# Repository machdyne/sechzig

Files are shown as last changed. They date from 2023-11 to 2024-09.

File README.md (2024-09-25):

# Sechzig Compute Module

Sechzig is a work-in-progress compute module specification.

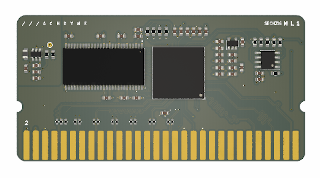
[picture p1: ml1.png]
Sechzig ML1


Sechzig modules have a 60-pin 2.54mm card edge connector.

This repo contains detailed specifications as well as relevant KiCad symbols and footprints.

## Specifications

### Signals

This section describes the signals from the perspective of the module when paired with [Mozart](https://github.com/machdyne/mozart).

| Signal | Voltage | Dir | Description |
| --- | --- | --- | --- |
| PWR5V0 | 5.0V | I | System power (2A max) |
| PWR3V3 | 3.3V | I | System power (1A max) |
| PWRIO | 2.5V - 3.3V | O | I/O power (1A max) |
| SYS\_PG | 3.3V | I | System power good |
| SYS\_RST\_N | PWRIO | I | System reset (active low) |
| SYS\_CLK48 | PWRIO | I | System clock (48MHz) |
| USBD\_Dx | 3.3V | IO | USB device interface |
| USBHx\_Dx | 3.3V | IO | USB host interfaces |
| AUD\_DAT | PWRIO | O | Audio data |
| AUD\_BCK | PWRIO | O | Audio clock |
| AUD\_WS | PWRIO | O | Audio word select |
| ETH\_TXx | PWRIO | O | Ethernet RMII PHY transmit data |
| ETH\_RXx | PWRIO | I | Ethernet RMII PHY receive data |
| ETH\_TXEN | PWRIO | O | Ethernet RMII PHY transmit enable |
| ETH\_CRS\_DV | PWRIO | I | Ethernet RMII PHY carrier sense / receive data valid |
| ETH\_RST\_N | PWRIO | O | Ethernet RMII PHY reset (active low) |
| ETH\_CLK50 | PWRIO | I | Ethernet/video clock (50MHz) |
| DDMI\_xx\_x | 3.3V | O | [DDMI](https://github.com/machdyne/ddmi) interface |
| Xx | PWRIO | IO | Extra link (see notes below) |
| SD\_CD\_N | 3.3V | I | SD card detect (active low) |
| SD\_SS | 3.3V | IO | SD slave select / DAT3 |
| SD\_SCK | 3.3V | O | SD clock |
| SD\_MISO | 3.3V | IO | SD data output / DAT0 |
| SD\_MOSI | 3.3V | IO | SD data input / CMD |
| SD\_D1 | 3.3V| IO | SD DAT1 |
| SD\_D2 | 3.3V | IO | SD DAT2 |
| JTAG\_xxx | PWRIO | IO | JTAG interface |
| UART\_TX | PWRIO | O | UART transmit |
| UART\_RX | PWRIO | I | UART receive |
| DSx\_x | 2.5V | IO | Experimental high-speed link (see notes below) |

#### Signal Notes

  * While all Sechzig modules should be compatible with [Mozart](https://github.com/machdyne/mozart), it is possible to develop alternative host boards that use some signals for other purposes (see [Vivaldi](https://github.com/machdyne/vivaldi) and [Chopin](https://github.com/machdyne/chopin)).

##### Extra Link (Xx) Notes

The purpose of the Xx signals is determined by the host board. For example, on Mozart:

| Signal | Description |
| --- | --- |
| XA | SPI MISO / I2C SCL |
| XB | SPI SCK / I2C SDA |
| XC | SPI MOSI |
| XD | SPI SS |

##### Experimental High-Speed Link (DSx) Notes

The DSx signal traces are routed as length-matched 100 ohm differential pairs. The following minimum required configuration should be supported by all modules, but some modules may have additional capabilities:

| Signal | Standard | Dir | Required | Description |
| --- | --- | --- | --- | --- |
| DS0\_x | LVDS25 | IO | N | Transmit and/or Receive |
| DS1\_x | LVDS25 | O | Y | Transmit |
| DS2\_x | LVDS25 | I | Y | Receive |

### Power

Sechzig modules can operate with 2.5V or 3.3V I/O (note that some signals must be 2.5V and 3.3V on all modules). Modules that use 3.3V I/O can simply connect PWRIO to PWR3V3. Modules that use 2.5V I/O must provide 2.5V on PWRIO.

### Module Dimensions

| Dimension | Value |
| --- | ----- |
| Width | 79mm |
| Height | 50mm max |
| Depth | 8mm max (4mm from center) |
| Card Edge Depth | 1.4mm - 1.6mm |

### Board Revisions

The version number can be found on the back of the module.

#### ML1

Product page for [Sechzig ML1](https://machdyne.com/product/sechzig-ml1-compute-module/).

| Revision | Stackup | Notes |
| --- | --- | ----- |
| ML1.1 | Aisler 4L | Initial production version; **Xx signals are not connected** |
| ML1.2 | Aisler 4L | Current production version; connects Xx signals; adds LED |

#### ML2

Product page for [Sechzig ML2](https://machdyne.com/product/sechzig-ml2-compute-module/).

| Revision | Stackup | Notes |
| --- | --- | ----- |
| ML2.0 | Aisler 6L | Initial production version |
| ML2.0B | JLC06161H-3313 | Current production version |

#### MX1

Product page for [Sechzig MX1](https://machdyne.com/product/sechzig-mx1-compute-module/).

| Revision | Stackup | Notes |
| --- | --- | ----- |
| MX1.1 | Aisler 4L | Initial production version |

#### MX2

Product page for [Sechzig MX2](https://machdyne.com/product/sechzig-mx2-compute-module/).

| Revision | Stackup | Notes |
| --- | --- | ----- |
| MX2.0 | JLC06161H-3313 | Initial production version |

## Funding

This project was partially funded through the NGI0 Entrust Fund, a fund established by NLnet with financial support from the European Commission's Next Generation Internet programme.

## License

This project is released under the [CERN-OHL-P](LICENSE.txt) license.

Note: You can use these designs for commercial purposes but we ask that instead of producing exact clones, that you either replace our trademarks and logos with your own or add your own next to ours.

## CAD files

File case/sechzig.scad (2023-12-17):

/*
 * Sechzig Case
 * Copyright (c) 2023 Lone Dynamics Corporation. All rights reserved.
 *
 * required hardware:
 *  - 2 x M3 x 16MM countersunk bolts
 *  - 2 x M3 nuts
 *
 */

$fn = 100;

board_depth = 1.6;
board_height = 40;

//translate([0,-2.5,6]) sechzig_module();
//rotate([180,0,180]) translate([0,0,-12]) sechzig_front();
sechzig_back();

module sechzig_module() {
	difference() {
		//color([0,1,0]) cube([79,50,8], center=true);
		color([0,1,0]) cube([79,board_height,8], center=true);
		translate([79/2,-50/2+15,-10]) cylinder(d=3, h=50);
		translate([-79/2,-50/2+15,-10]) cylinder(d=3, h=50);
	}
}

module sechzig_front() {
	
	//	color([0,1,0]) translate([0,0,6]) cube([80,53,board_depth], center=true);
	
	difference() {

		union() {
			translate([-95/2,-60/2+1.5,0]) roundedcube(95,board_height+10,6-(board_depth/2),2.5);
			translate([0,0,1.6]) cube([95+2,10,6-(board_depth/2)+2], center=true);
		}
				
		// module component cutout
		translate([0,0,6-(board_depth/2)]) cube([78,board_height+0.5,8.4], center=true);
		
		// bottom opening
		translate([0,-55/2+3.5,6]) cube([93,9.5,12-2], center=true);
	
		// vents
		translate([-5,12,0]) rotate([0,0,15]) cube([1,8,8], center=true);
		translate([0,12,0]) rotate([0,0,15]) cube([1,8,8], center=true);
		translate([5,12,0]) rotate([0,0,15]) cube([1,8,8], center=true);
		
		// bolt holes
		translate([-43.5,0,-2]) cylinder(d=3.2, h=100);
		translate([43.5,0,-2]) cylinder(d=3.2, h=100);
		
		// bolt countersink holes
		translate([-43.5,0,-2]) cylinder(d=6, h=1);
		translate([43.5,0,-2]) cylinder(d=6, h=1);
	
		rotate([0,180,0])
			translate([0,-2,1.5])
				linear_extrude(1)
					text("S E C H Z I G  M L 1", size=4, halign="center",
						font="Liberation Sans:style=Bold");

	}
		
}

module sechzig_back() {
		
//	color([0,1,0]) translate([0,0,6]) cube([80,53,board_depth], center=true);
	
	difference() {
		union() {
			translate([-95/2,-60/2+1.5,0]) roundedcube(95,board_height+10,6+(board_depth/2),2.5);
			translate([0,0,2.4]) cube([95+2,10,6+(board_depth/2)+2], center=true);
			
			// guide notches
			translate([20,-3.5,-1])
				cube([9.5,board_height+10,2], center=true);
				
			translate([-20,-3.5,-1])
				cube([9.5,board_height+10,2], center=true);

		}
		
		// module board cutout
		translate([0,0,6]) cube([79+0.5,board_height+0.5,board_depth], center=true);		

		// board notch adjacent cutouts
		translate([79/2-0.75,-55/2+15-2,3.8]) cube([2,2,5.6], center=true);
		translate([79/2-0.75,-55/2+15+2,3.8]) cube([2,2,5.6], center=true);
		translate([-79/2+0.75,-55/2+15-2,3.8]) cube([2,2,5.6], center=true);
		translate([-79/2+0.75,-55/2+15+2,3.8]) cube([2,2,5.6], center=true);
		
		
		// module component cutout
		translate([0,0,6]) cube([78,board_height+0.5,12-2], center=true);
		
		// bottom opening
		translate([0,-55/2+3.5,6]) cube([93,9.5,12-2], center=true);
		
		// vents
		translate([-5,12,0]) rotate([0,0,15]) cube([1,8,8], center=true);
		translate([0,12,0]) rotate([0,0,15]) cube([1,8,8], center=true);
		translate([5,12,0]) rotate([0,0,15]) cube([1,8,8], center=true);

		// bolt holes
		translate([-43.5,0,-2]) cylinder(d=3.2, h=100);
		translate([43.5,0,-2]) cylinder(d=3.2, h=100);
		
		// nut holes
		translate([-43.5,0,-2.5]) rotate([0,0,30]) cylinder(d=7, h=2.5, $fn=6);
		translate([43.5,0,-2.5]) rotate([0,0,30]) cylinder(d=7, h=2.5, $fn=6);
	
		rotate([0,180,0])
			translate([0,-2,1.5])
				linear_extrude(1)
					text("M L 1", size=4, halign="center",
						font="Liberation Sans:style=Bold");

	}

	// board notches
	translate([79/2+0.25,-55/2+15,3.8]) cylinder(d=2.75, h=6, center=true);
	translate([-79/2-0.25,-55/2+15,3.8]) cylinder(d=2.75, h=6, center=true);

}

// https://gist.github.com/tinkerology/ae257c5340a33ee2f149ff3ae97d9826
module roundedcube(xx, yy, height, radius)
{
    translate([0,0,height/2])
    hull()
    {
        translate([radius,radius,0])
        cylinder(height,radius,radius,true);

        translate([xx-radius,radius,0])
        cylinder(height,radius,radius,true);

        translate([xx-radius,yy-radius,0])
        cylinder(height,radius,radius,true);

        translate([radius,yy-radius,0])
        cylinder(height,radius,radius,true);
    }
}

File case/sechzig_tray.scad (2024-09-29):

/*
 * Sechzig Tray
 * Copyright (c) 2024 Lone Dynamics Corporation. All rights reserved.
 *
 */

$fn = 100;

board_length = 79 + 0.75;
board_thickness = 1.85;
board_width = 8 + 2;

boards = 8;

sechzig_tray();

module sechzig_tray() {
	
	length = board_length + 5;
	width = board_width * boards + 10;
	
	difference() {
		
		translate([-length/2,-width/2,-3/2]) roundedcube(length, width, 10, 5);
		
		for ( i = [0:boards-1] ) {
			translate([0,width/2-5-(i*board_width),13.5-8])
				cube([board_length, board_thickness, 10], center=true);
		}
		
		translate([length/2-20,-width/2+5,7.75])
			linear_extrude(2)
				text("S E C H Z I G", size=4, halign="center",
					font="Lato:style=Bold");

		translate([-length/2+10,-width/2+5,7.75])
			linear_extrude(2)
				text("/ / /", size=4, halign="center",
					font="Lato:style=Bold");
	
		
	}
	
}

// https://gist.github.com/tinkerology/ae257c5340a33ee2f149ff3ae97d9826
module roundedcube(xx, yy, height, radius)
{
    translate([0,0,height/2])
    hull()
    {
        translate([radius,radius,0])
        cylinder(height,radius,radius,true);

        translate([xx-radius,radius,0])
        cylinder(height,radius,radius,true);

        translate([xx-radius,yy-radius,0])
        cylinder(height,radius,radius,true);

        translate([radius,yy-radius,0])
        cylinder(height,radius,radius,true);
    }
}

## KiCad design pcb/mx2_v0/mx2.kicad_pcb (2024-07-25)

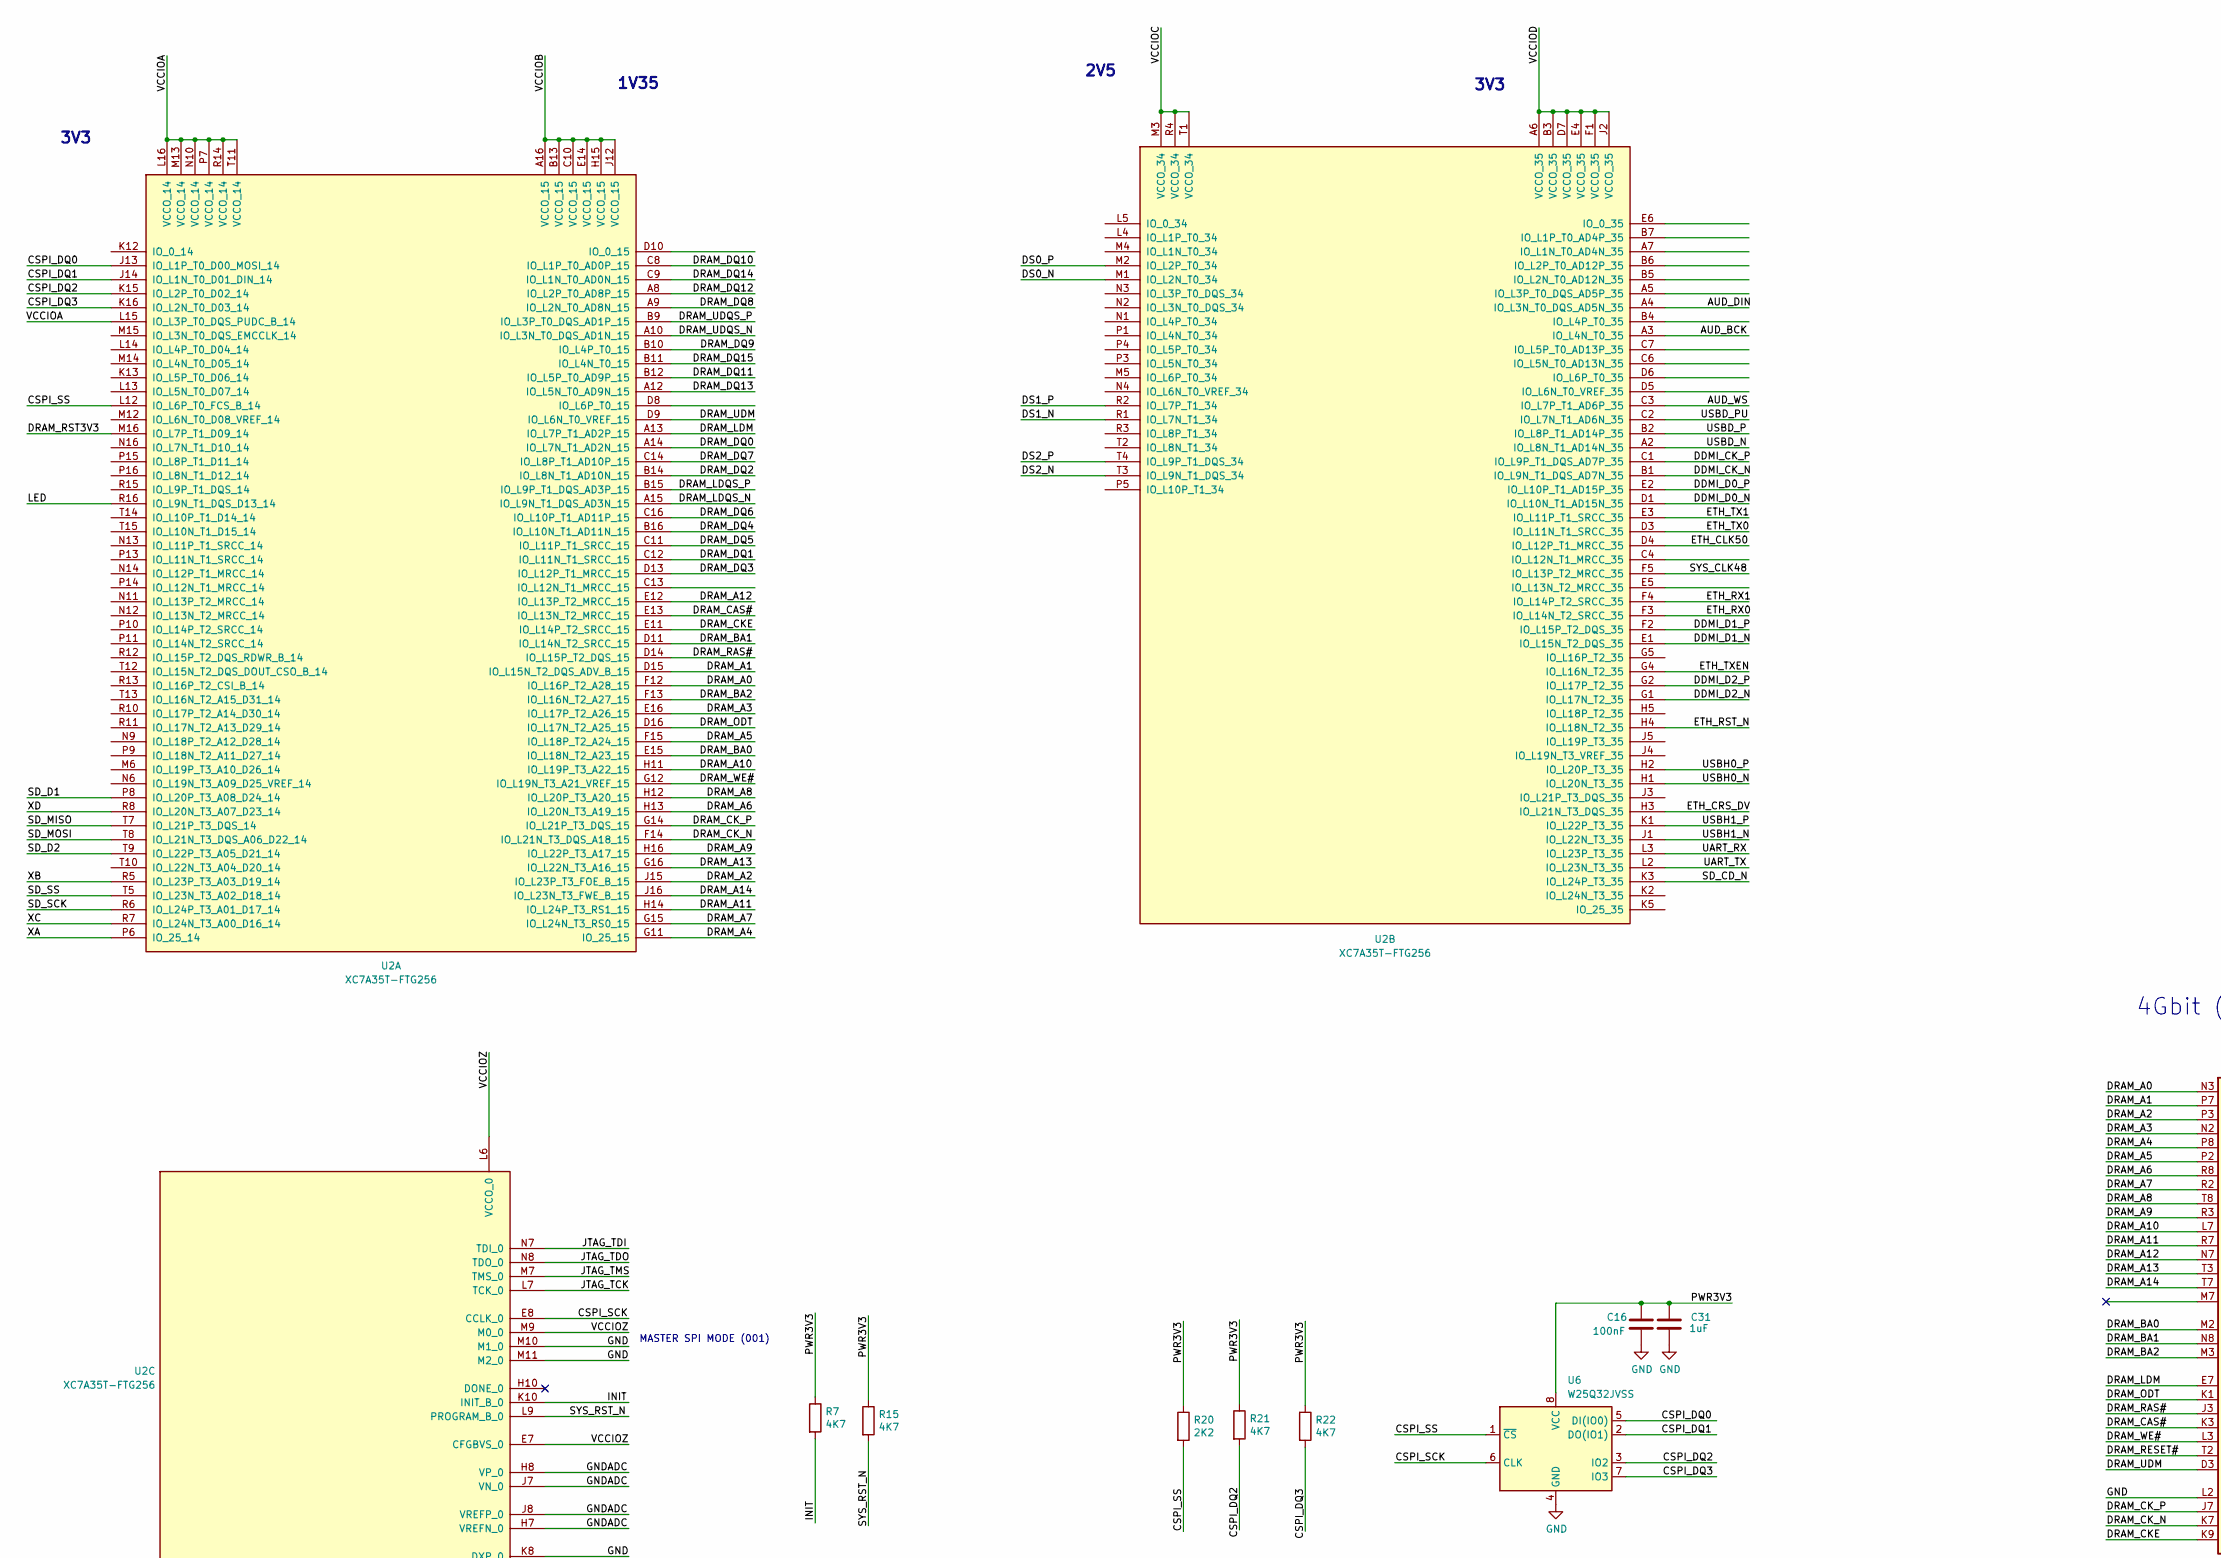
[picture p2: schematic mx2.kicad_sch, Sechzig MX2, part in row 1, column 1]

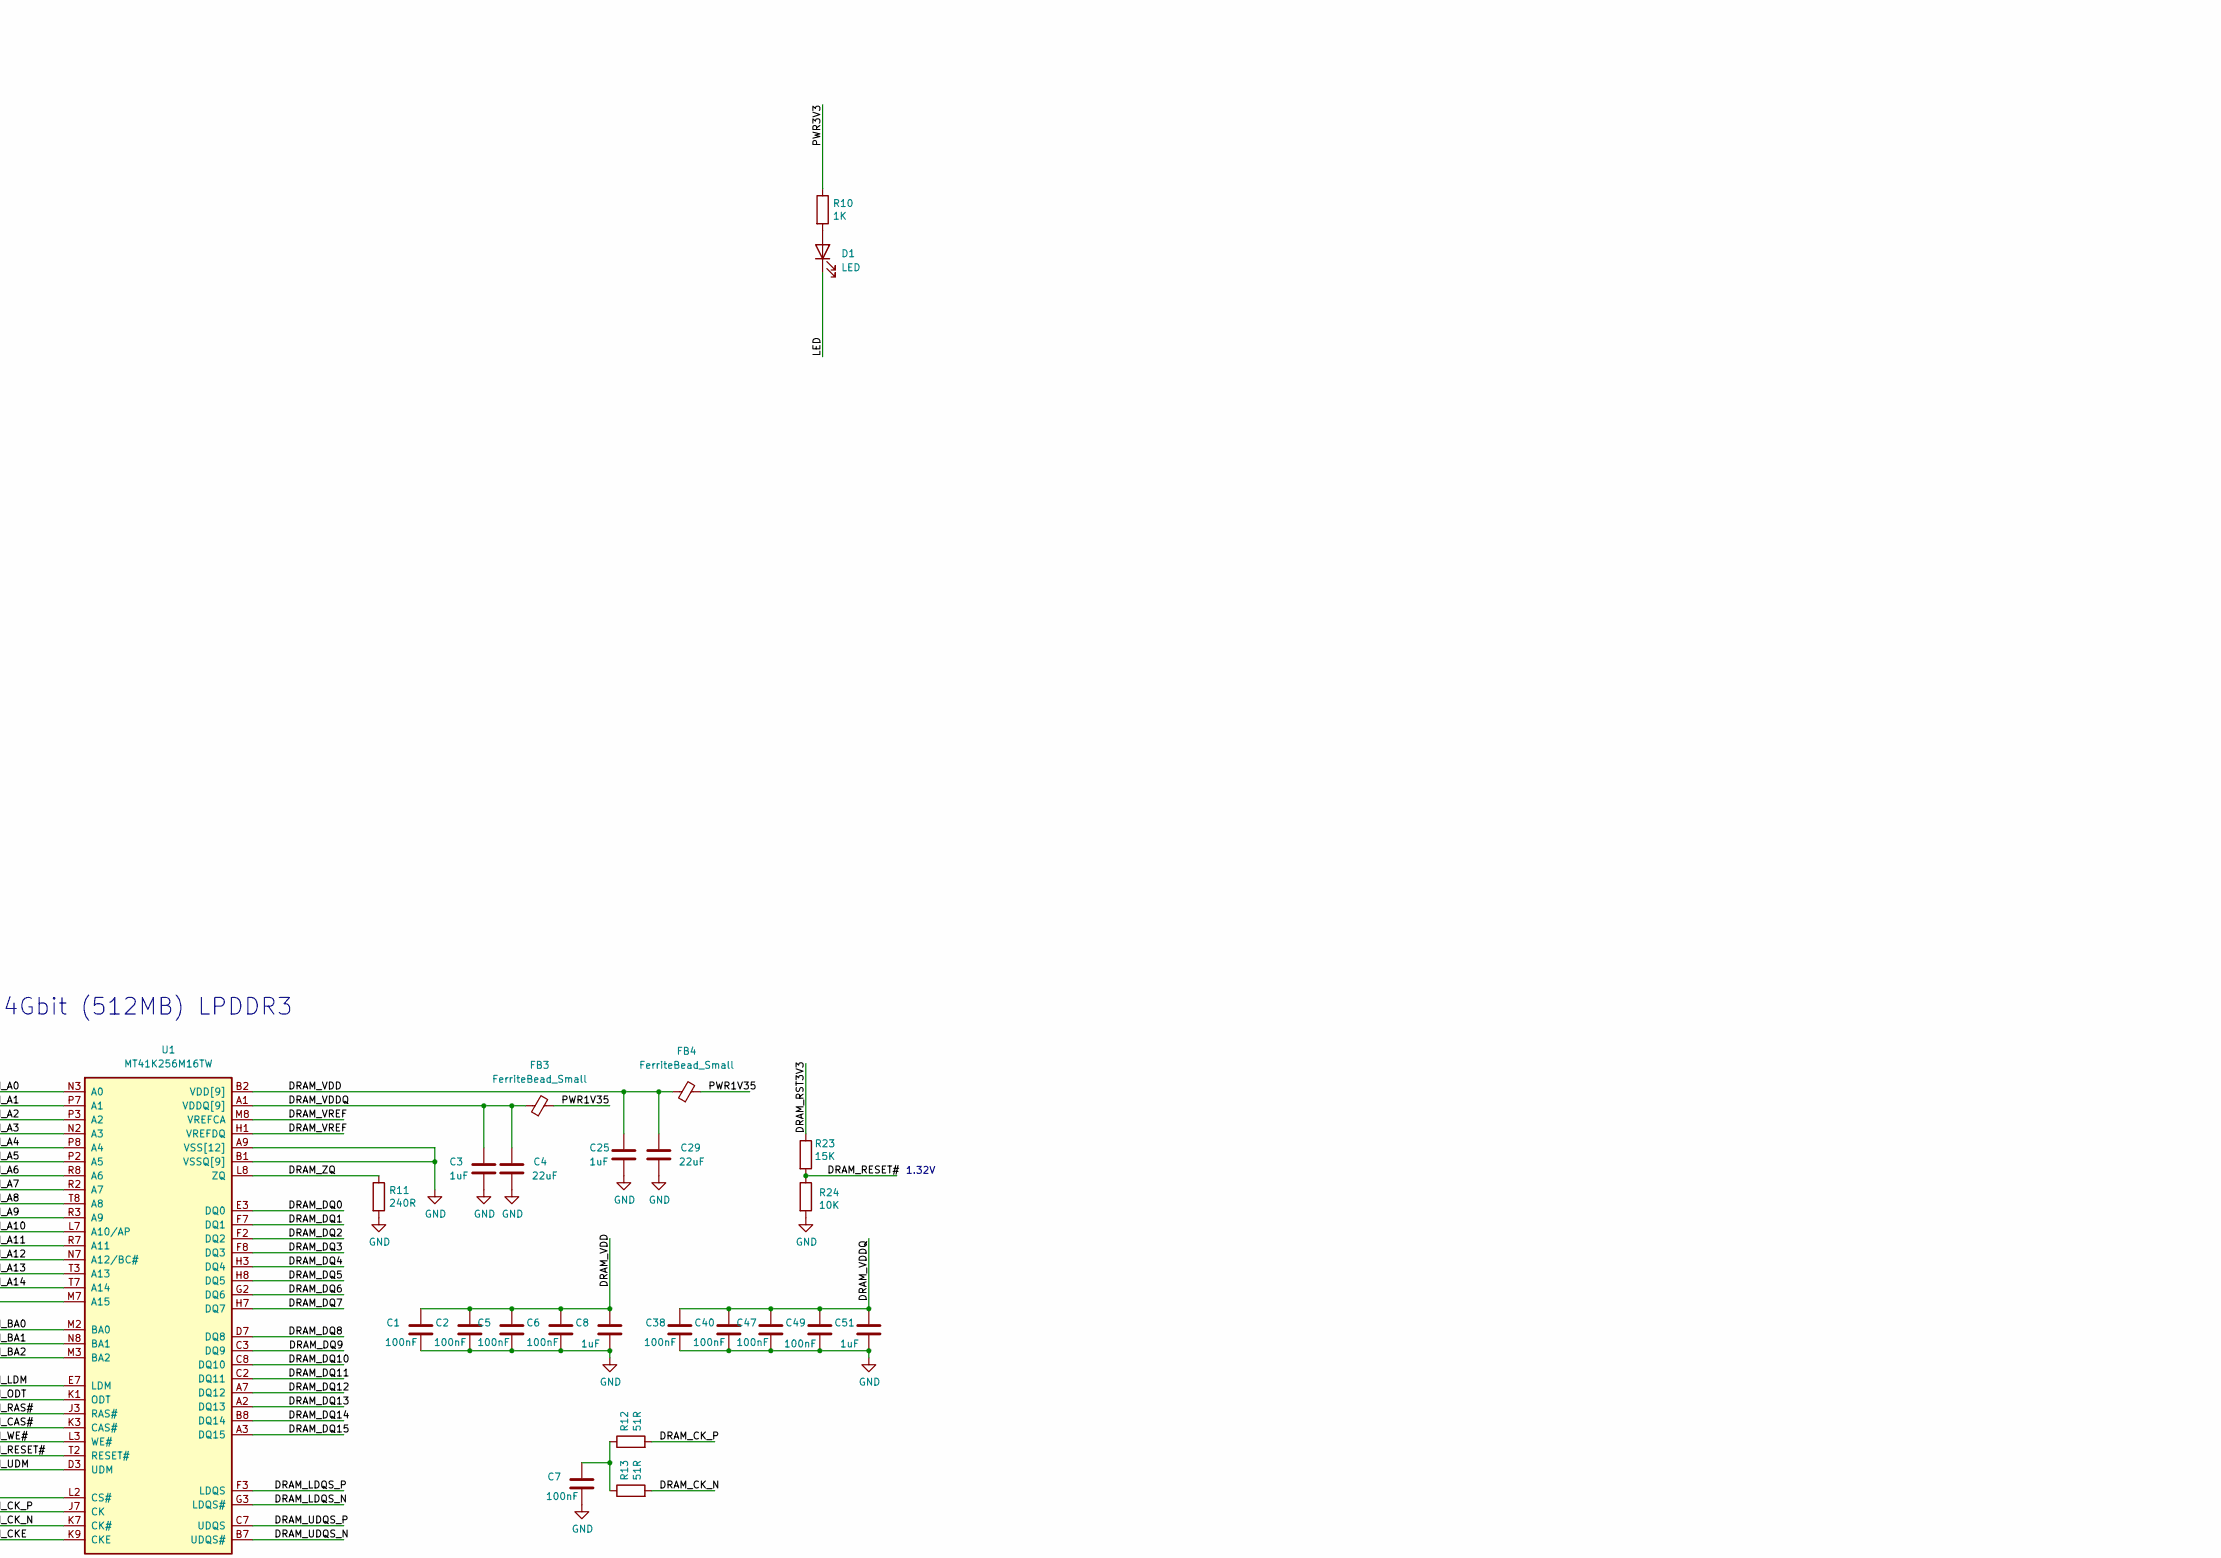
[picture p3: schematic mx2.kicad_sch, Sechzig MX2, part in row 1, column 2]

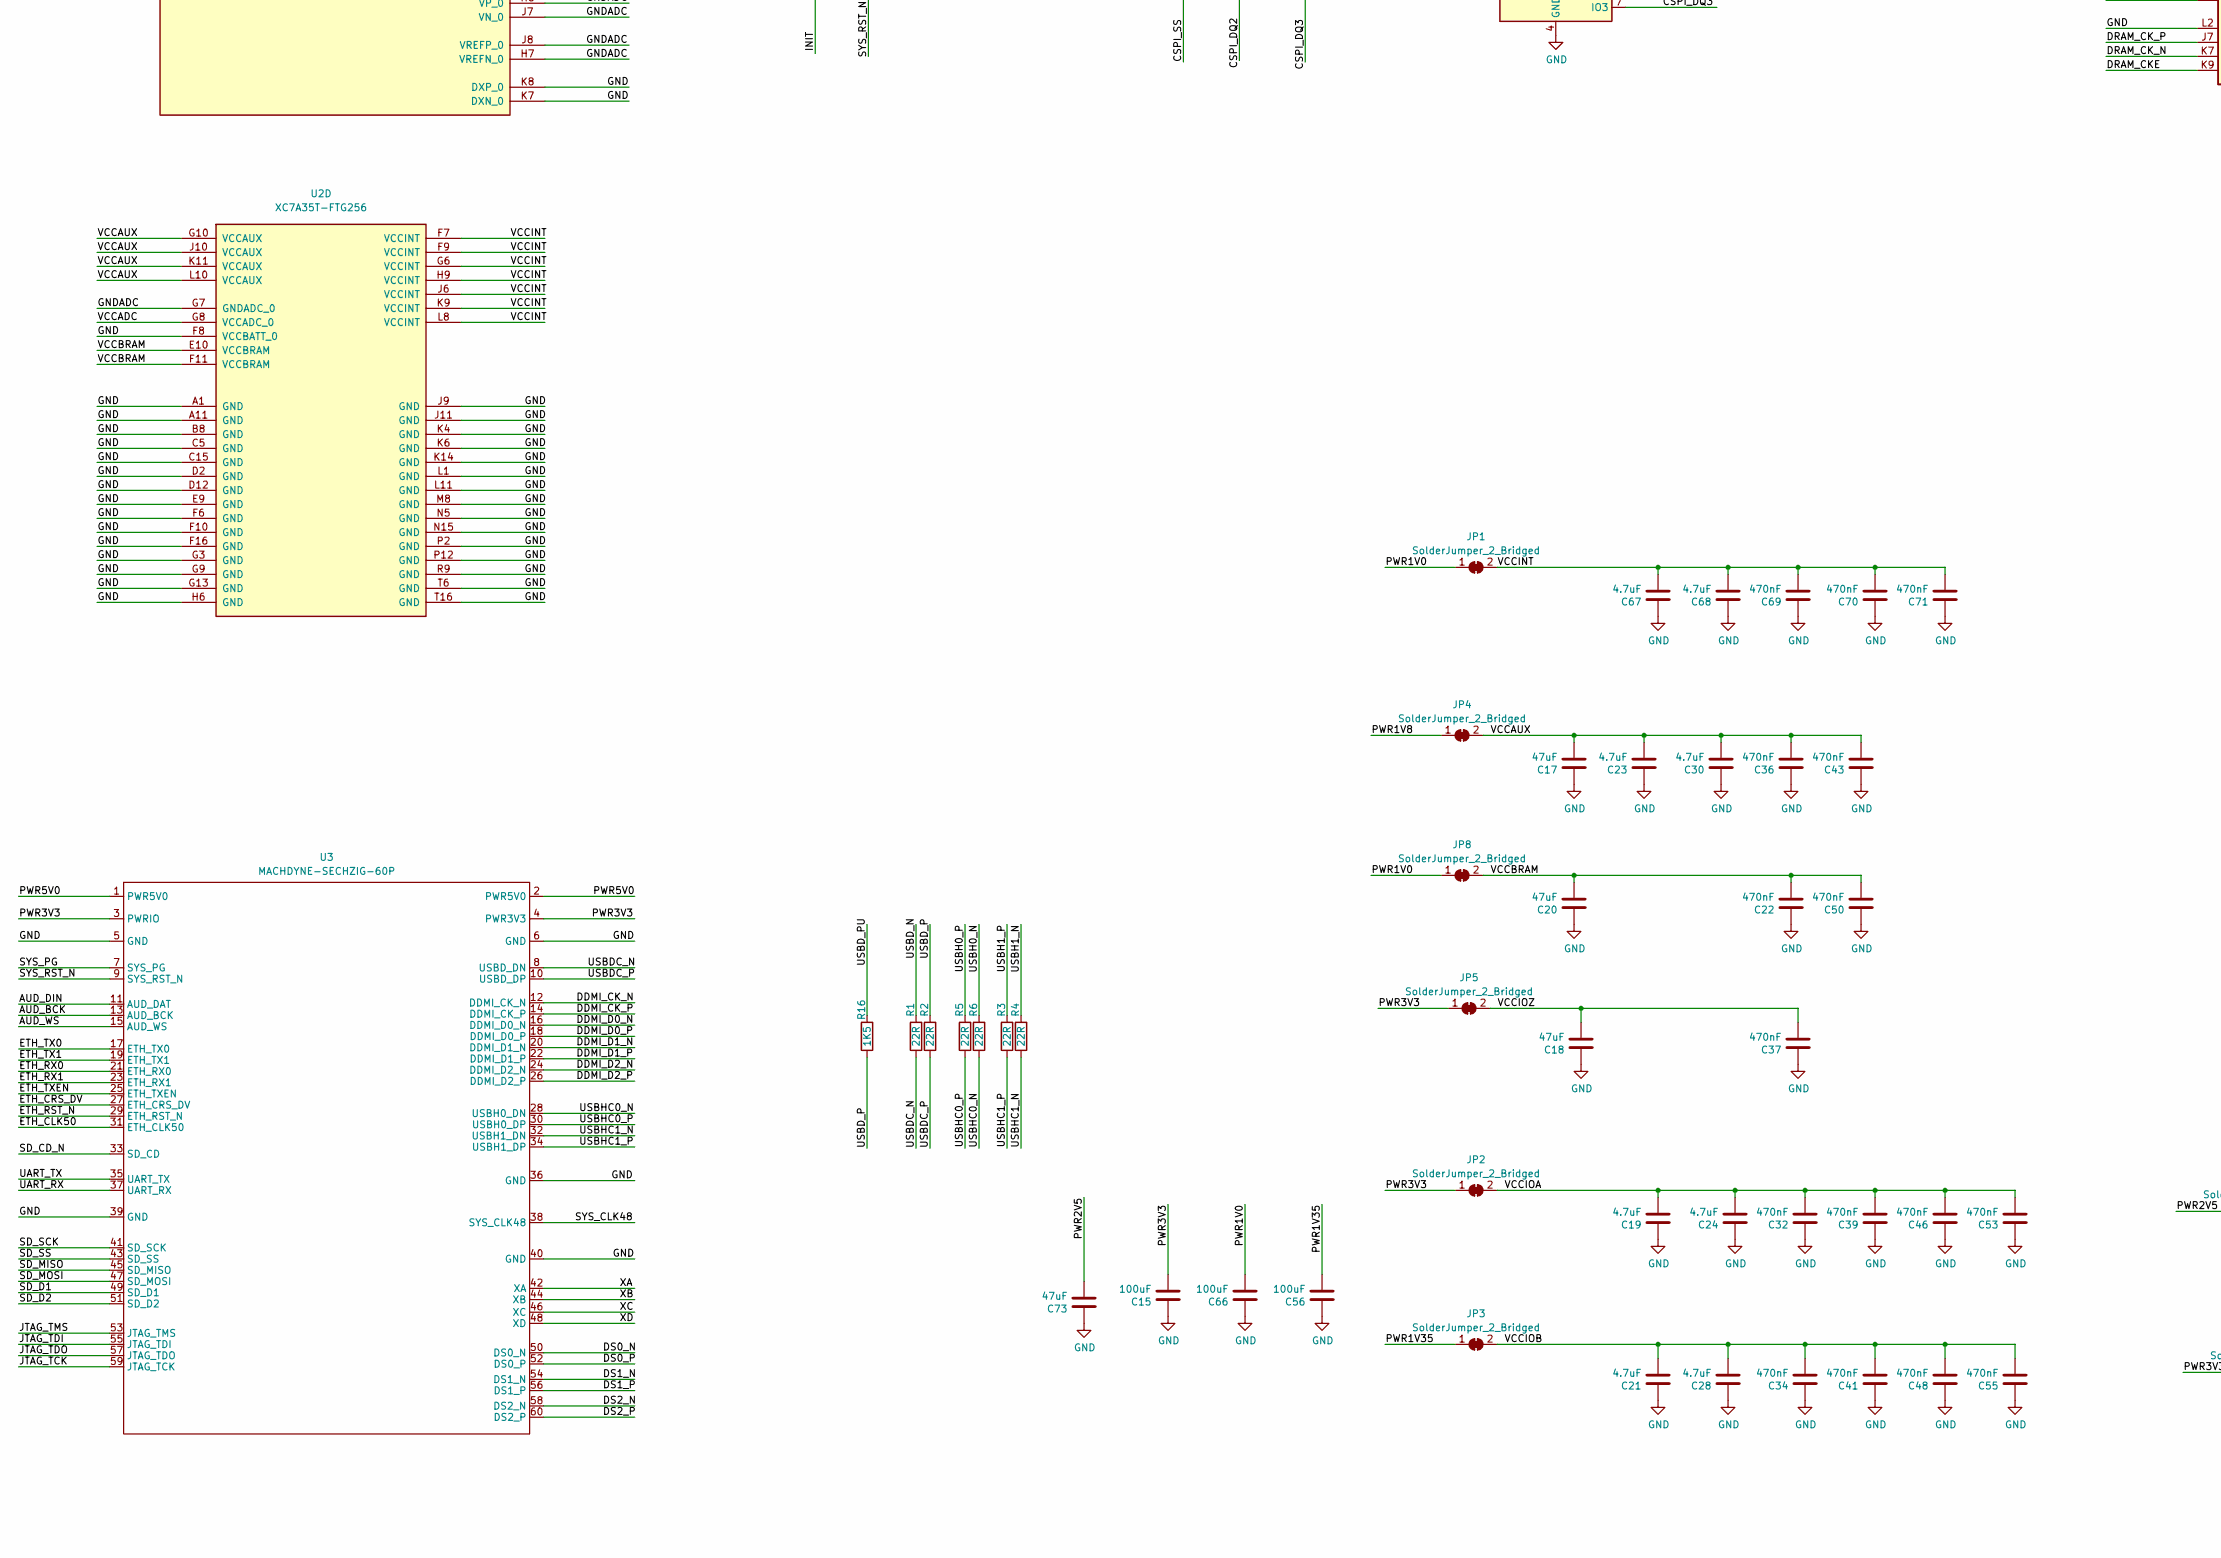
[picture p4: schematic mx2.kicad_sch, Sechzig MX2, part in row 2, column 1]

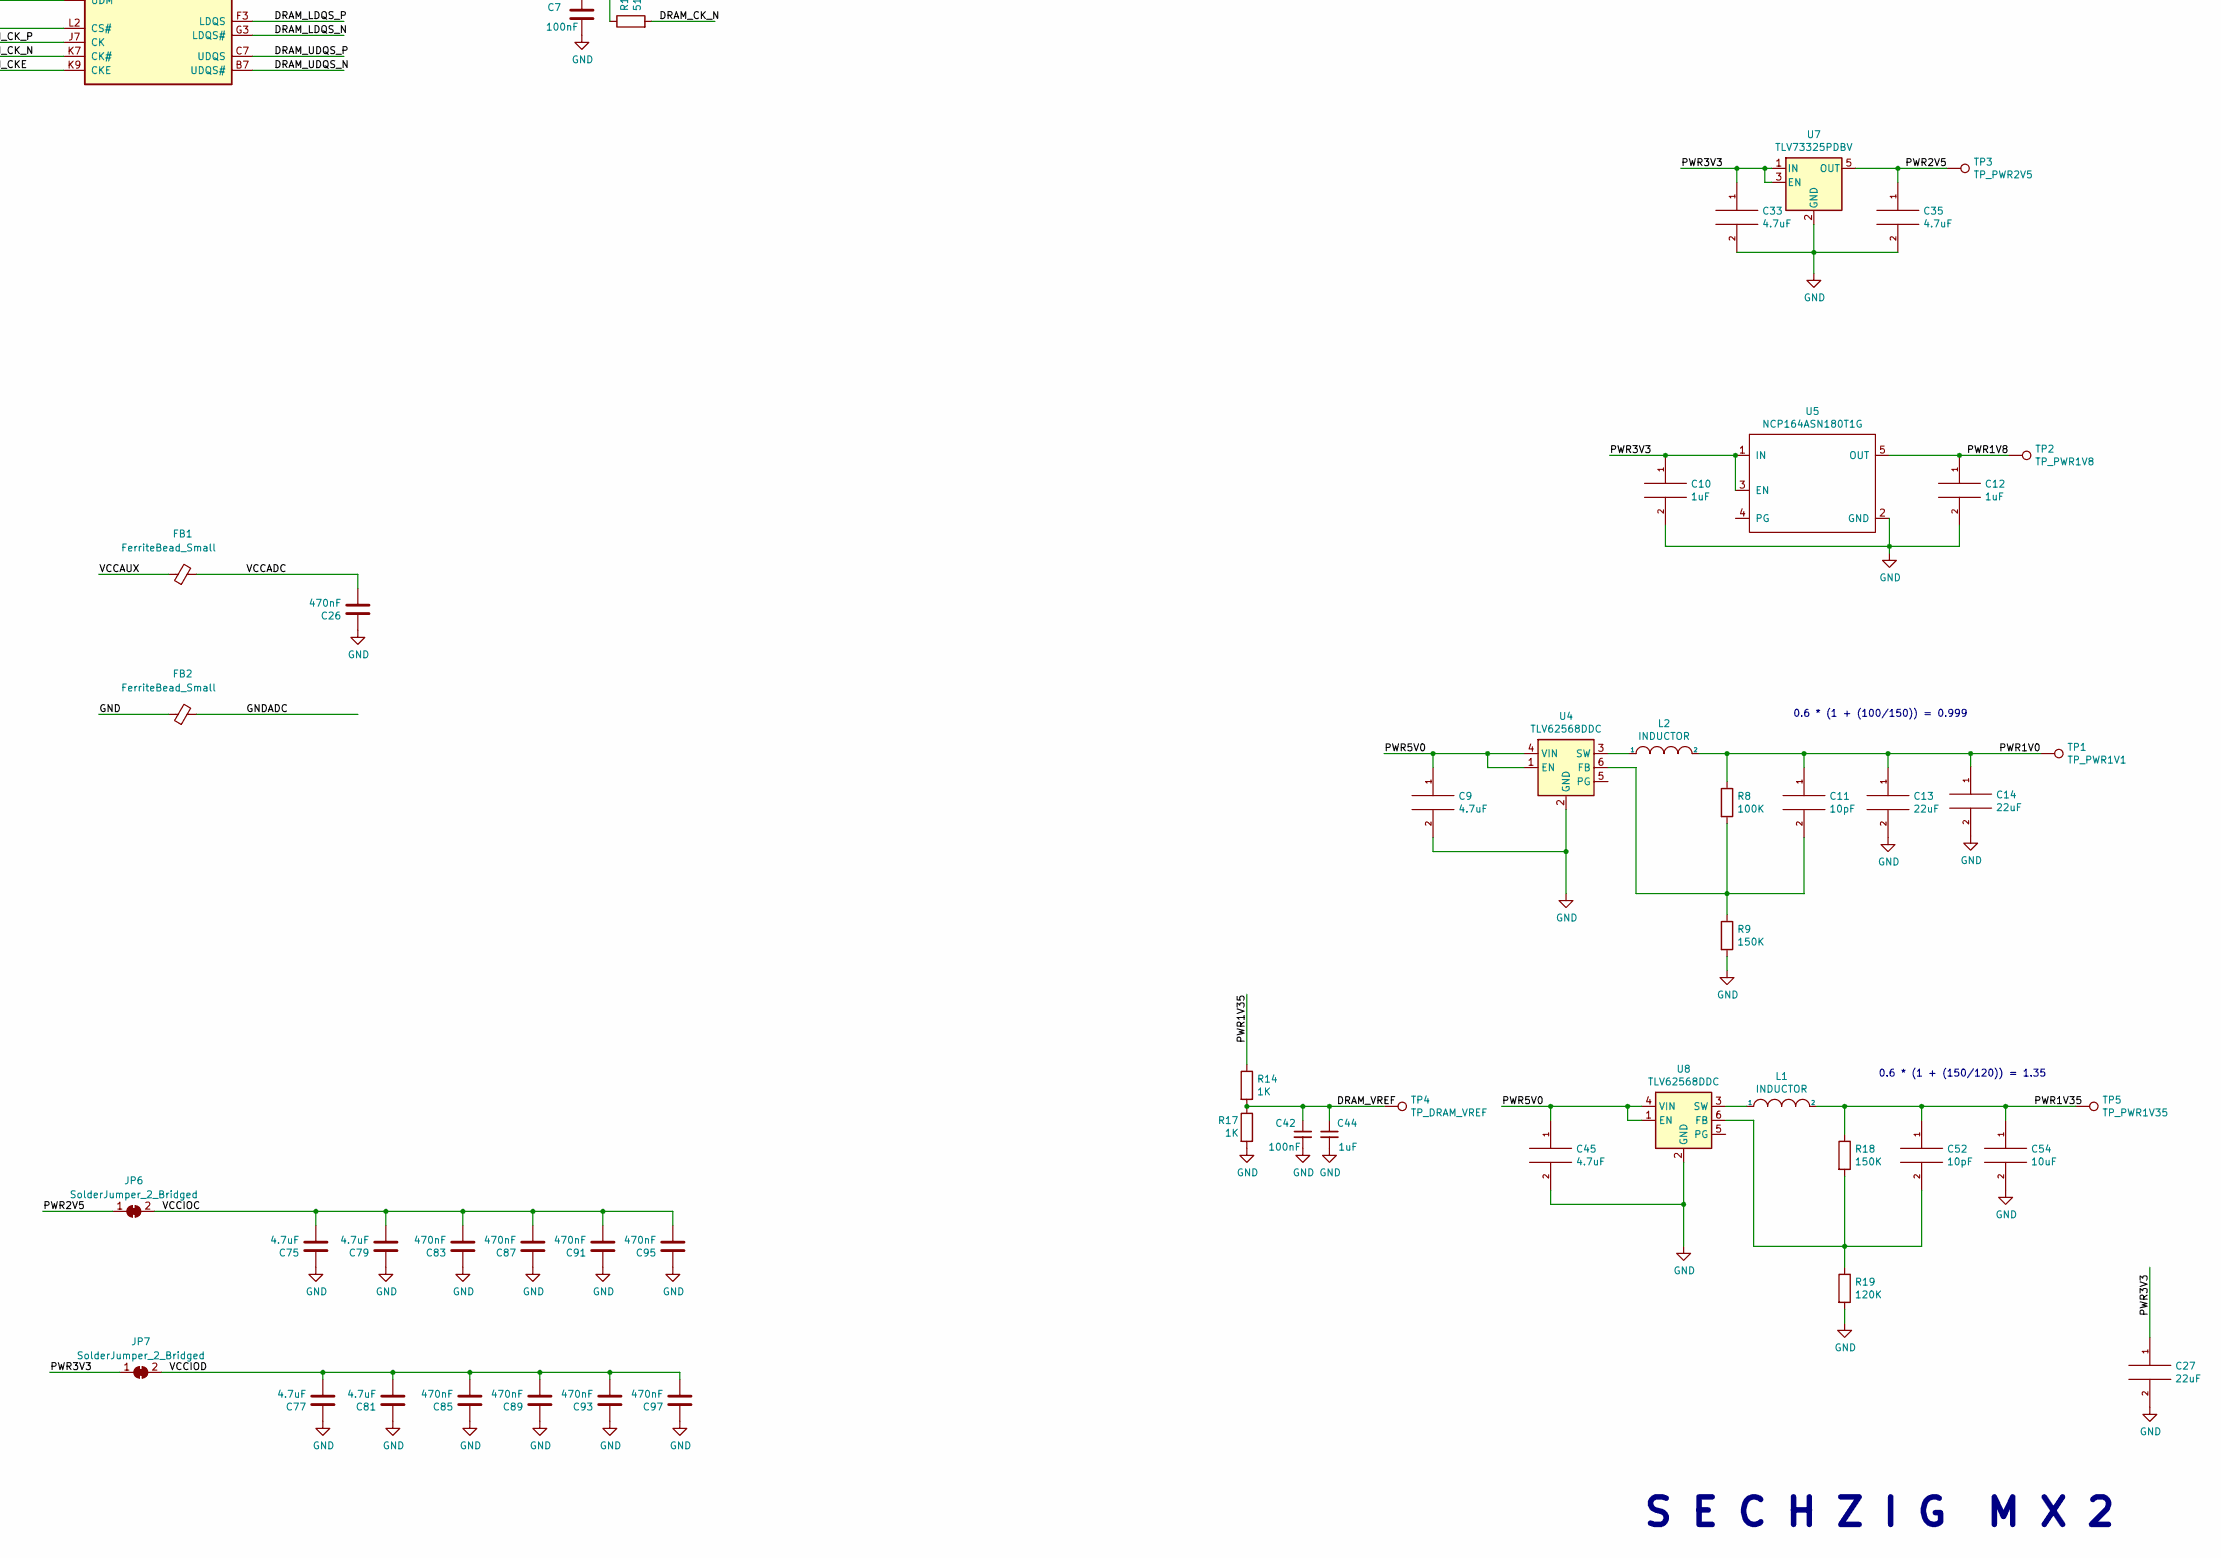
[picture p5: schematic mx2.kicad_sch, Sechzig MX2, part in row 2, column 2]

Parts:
C1, C2, C5, C6, C7, C38, C40, C47, C49: 100nF; C_0402_1005Metric
C3, C8, C25, C51: 1uF; C_0402_1005Metric
C4, C13, C14, C27, C29: 22uF; C_0603_1608Metric
C9, C19, C21, C23, C24, C28, C30, C33, C35, C45, C67, C68, C75, C77, C79, C81: 4.7uF; C_0603_1608Metric
C10, C12, C31, C44: 1uF; C_0603_1608Metric
C11, C52: 10pF; C_0603_1608Metric
C15, C56, C66: 100uF; C_1206_3216Metric
C16, C42: 100nF; C_0603_1608Metric
C17, C18, C20, C73: 47uF; C_0603_1608Metric
C22, C32, C34, C39, C41, C46, C83, C85, C87, C93: 470nF; C_0603_1608Metric
C26, C36, C37, C48, C53, C69, C70, C89, C91, C95, C97: 470nF; C_0402_1005Metric
C43, C50, C55, C71: 470nF; C_0201_0603Metric
C54: 10uF; C_0603_1608Metric
D1: LED; LED_0603_1608Metric
FB1, FB2: FerriteBead_Small; L_0402_1005Metric
FB3, FB4: FerriteBead_Small; R_0603_1608Metric
JP1, JP2, JP3, JP4, JP5, JP6, JP7, JP8: SolderJumper_2_Bridged; LD-NETTIE-0603
L1, L2: INDUCTOR; L_0805_2012Metric
R1, R2, R3, R4, R5, R6: 22R; R_0402_1005Metric
R7, R15, R21, R22: 4K7; R_0603_1608Metric
R8: 100K; R_0603_1608Metric
R9, R18: 150K; R_0603_1608Metric
R10, R14, R17: 1K; R_0603_1608Metric
R11: 240R; R_0603_1608Metric
R12, R13: 51R; R_0402_1005Metric
R16: 1K5; R_0402_1005Metric
R19: 120K; R_0603_1608Metric
R20: 2K2; R_0603_1608Metric
R23: 15K; R_0402_1005Metric
R24: 10K; R_0402_1005Metric
TP1: TP_PWR1V1; TestPoint_THTPad_D1.0mm_Drill0.5mm
TP2: TP_PWR1V8; TestPoint_THTPad_D1.0mm_Drill0.5mm
TP3: TP_PWR2V5; TestPoint_THTPad_D1.0mm_Drill0.5mm
TP4: TP_DRAM_VREF; TestPoint_THTPad_D1.0mm_Drill0.5mm
TP5: TP_PWR1V35; TestPoint_THTPad_D1.0mm_Drill0.5mm
U1: MT41K256M16TW; BGA-96_9.0x13.0mm_Layout2x3x16_P0.8mm_FIXED_SILK
U2: XC7A35T-FTG256; BGA-256_17.0x17.0mm_Layout16x16_P1.0mm_Ball0.5mm_Pad0.5mm_N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
U3: MACHDYNE-SECHZIG-60P; MACHDYNE_EDGE_60P
U4, U8: TLV62568DDC; SOT-23-6
U5: NCP164ASN180T1G; SOT-23-5
U6: W25Q32JVSS; SOIC-8_3.9x4.9mm_P1.27mm
U7: TLV73325PDBV; SOT-23-5

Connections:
/AUD_BCK: U2.A3 (IO_L4N_T0_35), U3.13 (AUD_BCK)
/AUD_DIN: U2.A4 (IO_L3N_T0_DQS_AD5N_35), U3.11 (AUD_DAT)
/AUD_WS: U2.C3 (IO_L7P_T1_AD6P_35), U3.15 (AUD_WS)
/CSPI_DQ0: U2.J13 (IO_L1P_T0_D00_MOSI_14), U6.5 (DI(IO0))
/CSPI_DQ1: U2.J14 (IO_L1N_T0_D01_DIN_14), U6.2 (DO(IO1))
/CSPI_DQ2: R21.2, U2.K15 (IO_L2P_T0_D02_14), U6.3 (IO2)
/CSPI_DQ3: R22.2, U2.K16 (IO_L2N_T0_D03_14), U6.7 (IO3)
/CSPI_SCK: U2.E8 (CCLK_0), U6.6 (CLK)
/CSPI_SS: R20.2, U2.L12 (IO_L6P_T0_FCS_B_14), U6.1 (~CS)
/DDMI_CK_N: U2.B1 (IO_L9N_T1_DQS_AD7N_35), U3.12 (DDMI_CK_N)
/DDMI_CK_P: U2.C1 (IO_L9P_T1_DQS_AD7P_35), U3.14 (DDMI_CK_P)
/DDMI_D0_N: U2.D1 (IO_L10N_T1_AD15N_35), U3.16 (DDMI_D0_N)
/DDMI_D0_P: U2.E2 (IO_L10P_T1_AD15P_35), U3.18 (DDMI_D0_P)
/DDMI_D1_N: U2.E1 (IO_L15N_T2_DQS_35), U3.20 (DDMI_D1_N)
/DDMI_D1_P: U2.F2 (IO_L15P_T2_DQS_35), U3.22 (DDMI_D1_P)
/DDMI_D2_N: U2.G1 (IO_L17N_T2_35), U3.24 (DDMI_D2_N)
/DDMI_D2_P: U2.G2 (IO_L17P_T2_35), U3.26 (DDMI_D2_P)
/DRAM_A0: U1.N3 (A0), U2.F12 (IO_L16P_T2_A28_15)
/DRAM_A1: U1.P7 (A1), U2.D15 (IO_L15N_T2_DQS_ADV_B_15)
/DRAM_A2: U1.P3 (A2), U2.J15 (IO_L23P_T3_FOE_B_15)
/DRAM_A3: U1.N2 (A3), U2.E16 (IO_L17P_T2_A26_15)
/DRAM_A4: U1.P8 (A4), U2.G11 (IO_25_15)
/DRAM_A5: U1.P2 (A5), U2.F15 (IO_L18P_T2_A24_15)
/DRAM_A6: U1.R8 (A6), U2.H13 (IO_L20N_T3_A19_15)
/DRAM_A7: U1.R2 (A7), U2.G15 (IO_L24N_T3_RS0_15)
/DRAM_A8: U1.T8 (A8), U2.H12 (IO_L20P_T3_A20_15)
/DRAM_A9: U1.R3 (A9), U2.H16 (IO_L22P_T3_A17_15)
/DRAM_A10: U1.L7 (A10/AP), U2.H11 (IO_L19P_T3_A22_15)
/DRAM_A11: U1.R7 (A11), U2.H14 (IO_L24P_T3_RS1_15)
/DRAM_A12: U1.N7 (A12/BC#), U2.E12 (IO_L13P_T2_MRCC_15)
/DRAM_A13: U1.T3 (A13), U2.G16 (IO_L22N_T3_A16_15)
/DRAM_A14: U1.T7 (A14), U2.J16 (IO_L23N_T3_FWE_B_15)
/DRAM_BA0: U1.M2 (BA0), U2.E15 (IO_L18N_T2_A23_15)
/DRAM_BA1: U1.N8 (BA1), U2.D11 (IO_L14N_T2_SRCC_15)
/DRAM_BA2: U1.M3 (BA2), U2.F13 (IO_L16N_T2_A27_15)
/DRAM_CAS#: U1.K3 (CAS#), U2.E13 (IO_L13N_T2_MRCC_15)
/DRAM_CKE: U1.K9 (CKE), U2.E11 (IO_L14P_T2_SRCC_15)
/DRAM_CK_N: R13.2, U1.K7 (CK#), U2.F14 (IO_L21N_T3_DQS_A18_15)
/DRAM_CK_P: R12.2, U1.J7 (CK), U2.G14 (IO_L21P_T3_DQS_15)
/DRAM_DQ0: U1.E3 (DQ0), U2.A14 (IO_L7N_T1_AD2N_15)
/DRAM_DQ1: U1.F7 (DQ1), U2.C12 (IO_L11N_T1_SRCC_15)
/DRAM_DQ2: U1.F2 (DQ2), U2.B14 (IO_L8N_T1_AD10N_15)
/DRAM_DQ3: U1.F8 (DQ3), U2.D13 (IO_L12P_T1_MRCC_15)
/DRAM_DQ4: U1.H3 (DQ4), U2.B16 (IO_L10N_T1_AD11N_15)
/DRAM_DQ5: U1.H8 (DQ5), U2.C11 (IO_L11P_T1_SRCC_15)
/DRAM_DQ6: U1.G2 (DQ6), U2.C16 (IO_L10P_T1_AD11P_15)
/DRAM_DQ7: U1.H7 (DQ7), U2.C14 (IO_L8P_T1_AD10P_15)
/DRAM_DQ8: U1.D7 (DQ8), U2.A9 (IO_L2N_T0_AD8N_15)
/DRAM_DQ9: U1.C3 (DQ9), U2.B10 (IO_L4P_T0_15)
/DRAM_DQ10: U1.C8 (DQ10), U2.C8 (IO_L1P_T0_AD0P_15)
/DRAM_DQ11: U1.C2 (DQ11), U2.B12 (IO_L5P_T0_AD9P_15)
/DRAM_DQ12: U1.A7 (DQ12), U2.A8 (IO_L2P_T0_AD8P_15)
/DRAM_DQ13: U1.A2 (DQ13), U2.A12 (IO_L5N_T0_AD9N_15)
/DRAM_DQ14: U1.B8 (DQ14), U2.C9 (IO_L1N_T0_AD0N_15)
/DRAM_DQ15: U1.A3 (DQ15), U2.B11 (IO_L4N_T0_15)
/DRAM_LDM: U1.E7 (LDM), U2.A13 (IO_L7P_T1_AD2P_15)
/DRAM_LDQS_N: U1.G3 (LDQS#), U2.A15 (IO_L9N_T1_DQS_AD3N_15)
/DRAM_LDQS_P: U1.F3 (LDQS), U2.B15 (IO_L9P_T1_DQS_AD3P_15)
/DRAM_ODT: U1.K1 (ODT), U2.D16 (IO_L17N_T2_A25_15)
/DRAM_RAS#: U1.J3 (RAS#), U2.D14 (IO_L15P_T2_DQS_15)
/DRAM_RESET#: R23.2, R24.1, U1.T2 (RESET#)
/DRAM_RST3V3: R23.1, U2.M16 (IO_L7P_T1_D09_14)
/DRAM_UDM: U1.D3 (UDM), U2.D9 (IO_L6N_T0_VREF_15)
/DRAM_UDQS_N: U1.B7 (UDQS#), U2.A10 (IO_L3N_T0_DQS_AD1N_15)
/DRAM_UDQS_P: U1.C7 (UDQS), U2.B9 (IO_L3P_T0_DQS_AD1P_15)
/DRAM_VDD: C1.1, C2.1, C5.1, C6.1, C8.1, C25.1, C29.1, FB4.1, U1.B2 (VDD[9]), U1.D9 (VDD), U1.G7 (VDD), U1.K2 (VDD), U1.K8 (VDD), U1.N1 (VDD), U1.N9 (VDD), U1.R1 (VDD), U1.R9 (VDD)
/DRAM_VDDQ: C3.1, C4.1, C38.1, C40.1, C47.1, C49.1, C51.1, FB3.1, U1.A1 (VDDQ[9]), U1.A8 (VDDQ), U1.C1 (VDDQ), U1.C9 (VDDQ), U1.D2 (VDDQ), U1.E9 (VDDQ), U1.F1 (VDDQ), U1.H2 (VDDQ), U1.H9 (VDDQ)
/DRAM_VREF: C42.1, C44.1, R14.2, R17.1, TP4.1, U1.H1 (VREFDQ), U1.M8 (VREFCA)
/DRAM_WE#: U1.L3 (WE#), U2.G12 (IO_L19N_T3_A21_VREF_15)
/DRAM_ZQ: R11.1, U1.L8 (ZQ)
/DS0_N: U2.M1 (IO_L2N_T0_34), U3.50 (DS0_N)
/DS0_P: U2.M2 (IO_L2P_T0_34), U3.52 (DS0_P)
/DS1_N: U2.R1 (IO_L7N_T1_34), U3.54 (DS1_N)
/DS1_P: U2.R2 (IO_L7P_T1_34), U3.56 (DS1_P)
/DS2_N: U2.T3 (IO_L9N_T1_DQS_34), U3.58 (DS2_N)
/DS2_P: U2.T4 (IO_L9P_T1_DQS_34), U3.60 (DS2_P)
/ETH_CLK50: U2.D4 (IO_L12P_T1_MRCC_35), U3.31 (ETH_CLK50)
/ETH_CRS_DV: U2.H3 (IO_L21N_T3_DQS_35), U3.27 (ETH_CRS_DV)
/ETH_RST_N: U2.H4 (IO_L18N_T2_35), U3.29 (ETH_RST_N)
/ETH_RX0: U2.F3 (IO_L14N_T2_SRCC_35), U3.21 (ETH_RX0)
/ETH_RX1: U2.F4 (IO_L14P_T2_SRCC_35), U3.23 (ETH_RX1)
/ETH_TX0: U2.D3 (IO_L11N_T1_SRCC_35), U3.17 (ETH_TX0)
/ETH_TX1: U2.E3 (IO_L11P_T1_SRCC_35), U3.19 (ETH_TX1)
/ETH_TXEN: U2.G4 (IO_L16N_T2_35), U3.25 (ETH_TXEN)
/GNDADC: FB2.2, U2.G7 (GNDADC_0), U2.H7 (VREFN_0), U2.H8 (VP_0), U2.J7 (VN_0), U2.J8 (VREFP_0)
/INIT: R7.2, U2.K10 (INIT_B_0)
/JTAG_TCK: U2.L7 (TCK_0), U3.59 (JTAG_TCK)
/JTAG_TDI: U2.N7 (TDI_0), U3.55 (JTAG_TDI)
/JTAG_TDO: U2.N8 (TDO_0), U3.57 (JTAG_TDO)
/JTAG_TMS: U2.M7 (TMS_0), U3.53 (JTAG_TMS)
/LED: D1.1 (K), U2.R16 (IO_L9N_T1_DQS_D13_14)
/PWR1V0: C11.1, C13.1, C14.1, C66.2, JP1.1 (A), JP8.1 (A), L2.2, R8.1, TP1.1
/PWR1V8: C12.1, JP4.1 (A), TP2.1, U5.5 (OUT)
/PWR1V35: C52.1, C54.1, C56.2, FB3.2, FB4.2, JP3.1 (A), L1.2, R14.1, R18.1, TP5.1
/PWR2V5: C35.1, C73.2, JP6.1 (A), TP3.1, U7.5 (OUT)
/PWR3V3: C10.1, C15.2, C16.1, C27.1, C31.1, C33.1, JP2.1 (A), JP5.1 (A), JP7.1 (A), R7.1, R10.1, R15.1, R20.1, R21.1, R22.1, U3.3 (PWRIO), U3.4 (PWR3V3), U5.1 (IN), U5.3 (EN), U6.8 (VCC), U7.1 (IN), U7.3 (EN)
/PWR5V0: C9.1, C45.1, U3.1 (PWR5V0), U3.2 (PWR5V0), U4.1 (EN), U4.4 (VIN), U8.1 (EN), U8.4 (VIN)
/SD_CD_N: U2.K3 (IO_L24P_T3_35), U3.33 (SD_CD)
/SD_D1: U2.P8 (IO_L20P_T3_A08_D24_14), U3.49 (SD_D1)
/SD_D2: U2.T9 (IO_L22P_T3_A05_D21_14), U3.51 (SD_D2)
/SD_MISO: U2.T7 (IO_L21P_T3_DQS_14), U3.45 (SD_MISO)
/SD_MOSI: U2.T8 (IO_L21N_T3_DQS_A06_D22_14), U3.47 (SD_MOSI)
/SD_SCK: U2.R6 (IO_L24P_T3_A01_D17_14), U3.41 (SD_SCK)
/SD_SS: U2.T5 (IO_L23N_T3_A02_D18_14), U3.43 (SD_SS)
/SYS_CLK48: U2.F5 (IO_L13P_T2_MRCC_35), U3.38 (SYS_CLK48)
/SYS_PG: U3.7 (SYS_PG)
/SYS_RST_N: R15.2, U2.L9 (PROGRAM_B_0), U3.9 (SYS_RST_N)
/UART_RX: U2.L3 (IO_L23P_T3_35), U3.37 (UART_RX)
/UART_TX: U2.L2 (IO_L23N_T3_35), U3.35 (UART_TX)
/USBDC_N: R1.1, U3.8 (USBD_DN)
/USBDC_P: R2.1, U3.10 (USBD_DP)
/USBD_N: R1.2, U2.A2 (IO_L8N_T1_AD14N_35)
/USBD_P: R2.2, R16.1, U2.B2 (IO_L8P_T1_AD14P_35)
/USBD_PU: R16.2, U2.C2 (IO_L7N_T1_AD6N_35)
/USBH0_N: R6.2, U2.H1 (IO_L20N_T3_35)
/USBH0_P: R5.2, U2.H2 (IO_L20P_T3_35)
/USBH1_N: R4.2, U2.J1 (IO_L22N_T3_35)
/USBH1_P: R3.2, U2.K1 (IO_L22P_T3_35)
/USBHC0_N: R6.1, U3.28 (USBH0_DN)
/USBHC0_P: R5.1, U3.30 (USBH0_DP)
/USBHC1_N: R4.1, U3.32 (USBH1_DN)
/USBHC1_P: R3.1, U3.34 (USBH1_DP)
/VCCADC: C26.2, FB1.2, U2.G8 (VCCADC_0)
/VCCAUX: C17.2, C23.2, C30.2, C36.2, C43.2, FB1.1, JP4.2 (B), U2.G10 (VCCAUX), U2.J10 (VCCAUX), U2.K11 (VCCAUX), U2.L10 (VCCAUX)
/VCCBRAM: C20.2, C22.2, C50.2, JP8.2 (B), U2.E10 (VCCBRAM), U2.F11 (VCCBRAM)
/VCCINT: C67.2, C68.2, C69.2, C70.2, C71.2, JP1.2 (B), U2.F7 (VCCINT), U2.F9 (VCCINT), U2.G6 (VCCINT), U2.H9 (VCCINT), U2.J6 (VCCINT), U2.K9 (VCCINT), U2.L8 (VCCINT)
/VCCIOA: C19.2, C24.2, C32.2, C39.2, C46.2, C53.2, JP2.2 (B), U2.L15 (IO_L3P_T0_DQS_PUDC_B_14), U2.L16 (VCCO_14), U2.M13 (VCCO_14), U2.N10 (VCCO_14), U2.P7 (VCCO_14), U2.R14 (VCCO_14), U2.T11 (VCCO_14)
/VCCIOB: C21.2, C28.2, C34.2, C41.2, C48.2, C55.2, JP3.2 (B), U2.A16 (VCCO_15), U2.B13 (VCCO_15), U2.C10 (VCCO_15), U2.E14 (VCCO_15), U2.H15 (VCCO_15), U2.J12 (VCCO_15)
/VCCIOC: C75.2, C79.2, C83.2, C87.2, C91.2, C95.2, JP6.2 (B), U2.M3 (VCCO_34), U2.R4 (VCCO_34), U2.T1 (VCCO_34)
/VCCIOD: C77.2, C81.2, C85.2, C89.2, C93.2, C97.2, JP7.2 (B), U2.A6 (VCCO_35), U2.B3 (VCCO_35), U2.D7 (VCCO_35), U2.E4 (VCCO_35), U2.F1 (VCCO_35), U2.J2 (VCCO_35)
/VCCIOZ: C18.2, C37.2, JP5.2 (B), U2.E7 (CFGBVS_0), U2.L6 (VCCO_0), U2.M9 (M0_0)
/XA: U2.P6 (IO_25_14), U3.42 (XA)
/XB: U2.R5 (IO_L23P_T3_A03_D19_14), U3.44 (XB)
/XC: U2.R7 (IO_L24N_T3_A00_D16_14), U3.46 (XC)
/XD: U2.R8 (IO_L20N_T3_A07_D23_14), U3.48 (XD)
GND: C1.2, C2.2, C3.2, C4.2, C5.2, C6.2, C7.2, C8.2, C9.2, C10.2, C12.2, C13.2, C14.2, C15.1, C16.2, C17.1, C18.1, C19.1, C20.1, C21.1, C22.1, C23.1, C24.1, C25.2, C26.1, C27.2, C28.1, C29.2, C30.1, C31.2, C32.1, C33.2, C34.1, C35.2, C36.1, C37.1, C38.2, C39.1, C40.2, C41.1, C42.2, C43.1, C44.2, C45.2, C46.1, C47.2, C48.1, C49.2, C50.1, C51.2, C53.1, C54.2, C55.1, C56.1, C66.1, C67.1, C68.1, C69.1, C70.1, C71.1, C73.1, C75.1, C77.1, C79.1, C81.1, C83.1, C85.1, C87.1, C89.1, C91.1, C93.1, C95.1, C97.1, FB2.1, R9.2, R11.2, R17.2, R19.2, R24.2, U1.A9 (VSS[12]), U1.B1 (VSSQ[9]), U1.B3 (VSS), U1.B9 (VSSQ), U1.D1 (VSSQ), U1.D8 (VSSQ), U1.E1 (VSS), U1.E2 (VSSQ), U1.E8 (VSSQ), U1.F9 (VSSQ), U1.G1 (VSSQ), U1.G9 (VSSQ), U1.J2 (VSS), U1.J8 (VSS), U1.L2 (CS#), U1.M1 (VSS), U1.M9 (VSS), U1.P1 (VSS), U1.P9 (VSS), U1.T1 (VSS), U1.T9 (VSS), U2.A1 (GND), U2.A11 (GND), U2.B8 (GND), U2.C5 (GND), U2.C15 (GND), U2.D2 (GND), U2.D12 (GND), U2.E9 (GND), U2.F6 (GND), U2.F8 (VCCBATT_0), U2.F10 (GND), U2.F16 (GND), U2.G3 (GND), U2.G9 (GND), U2.G13 (GND), U2.H6 (GND), U2.J9 (GND), U2.J11 (GND), U2.K4 (GND), U2.K6 (GND), U2.K7 (DXN_0), U2.K8 (DXP_0), U2.K14 (GND), U2.L1 (GND), U2.L11 (GND), U2.M8 (GND), U2.M10 (M1_0), U2.M11 (M2_0), U2.N5 (GND), U2.N15 (GND), U2.P2 (GND), U2.P12 (GND), U2.R9 (GND), U2.T6 (GND), U2.T16 (GND), U3.5 (GND), U3.6 (GND), U3.36 (GND), U3.39 (GND), U3.40 (GND), U4.2 (GND), U5.2 (GND), U6.4 (GND), U7.2 (GND), U8.2 (GND)
unnamed: C7.1, R12.1, R13.1
unnamed: D1.2 (A), R10.2
unnamed: C11.2, R8.2, R9.1, U4.6 (FB)
unnamed: L2.1, U4.3 (SW)
unnamed: C52.2, R18.2, R19.1, U8.6 (FB)
unnamed: L1.1, U8.3 (SW)

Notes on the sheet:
3V3
S E C H Z I G M X 2
1V35
1.32V
0.6 * (1 + (100/150)) = 0.999
4Gbit (512MB) LPDDR3
0.6 * (1 + (150/120)) = 1.35
MASTER SPI MODE (001)
2V5

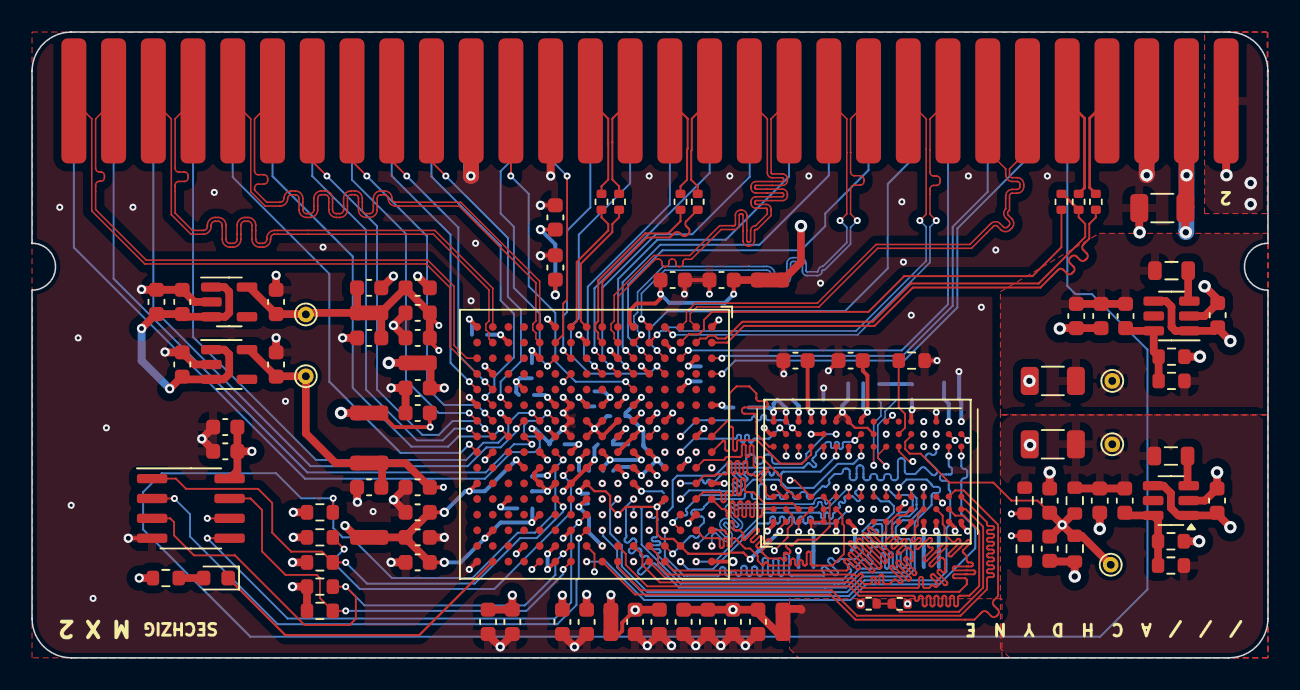
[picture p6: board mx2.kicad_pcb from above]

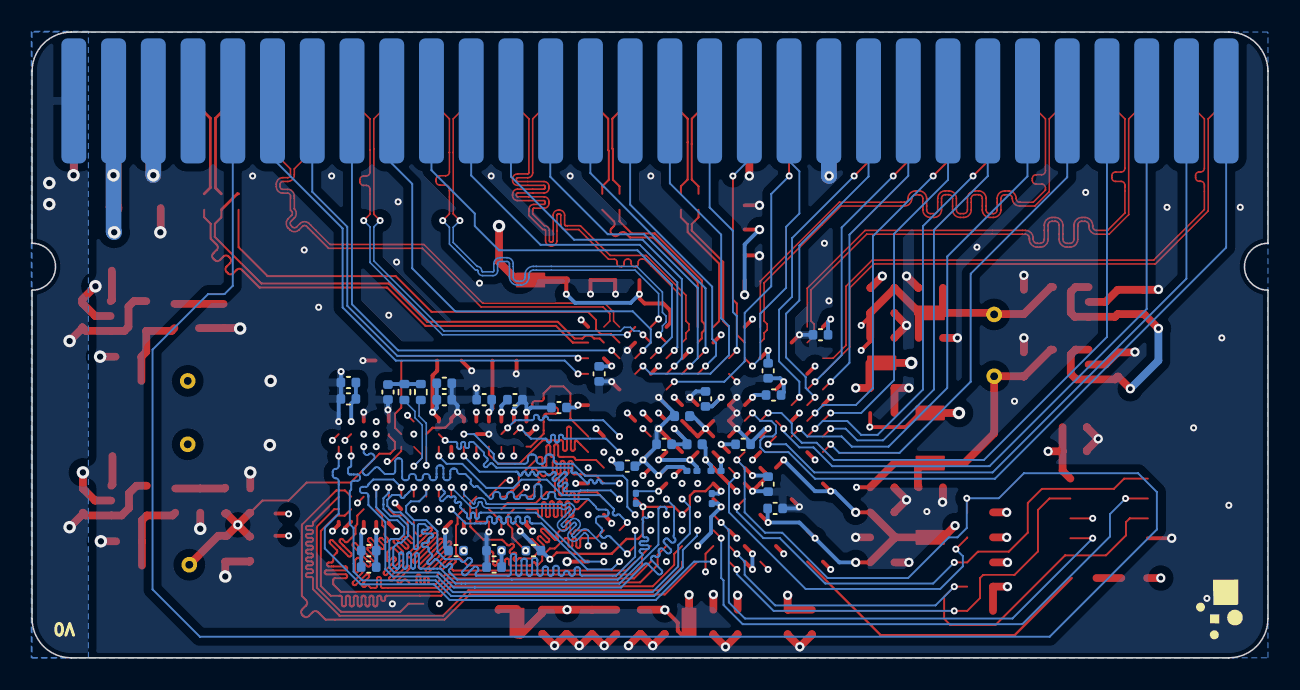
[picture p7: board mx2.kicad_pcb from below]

Board: 6 copper layers, 79.0 x 40.0 mm, 127 parts (33 on the bottom side), 141 nets.

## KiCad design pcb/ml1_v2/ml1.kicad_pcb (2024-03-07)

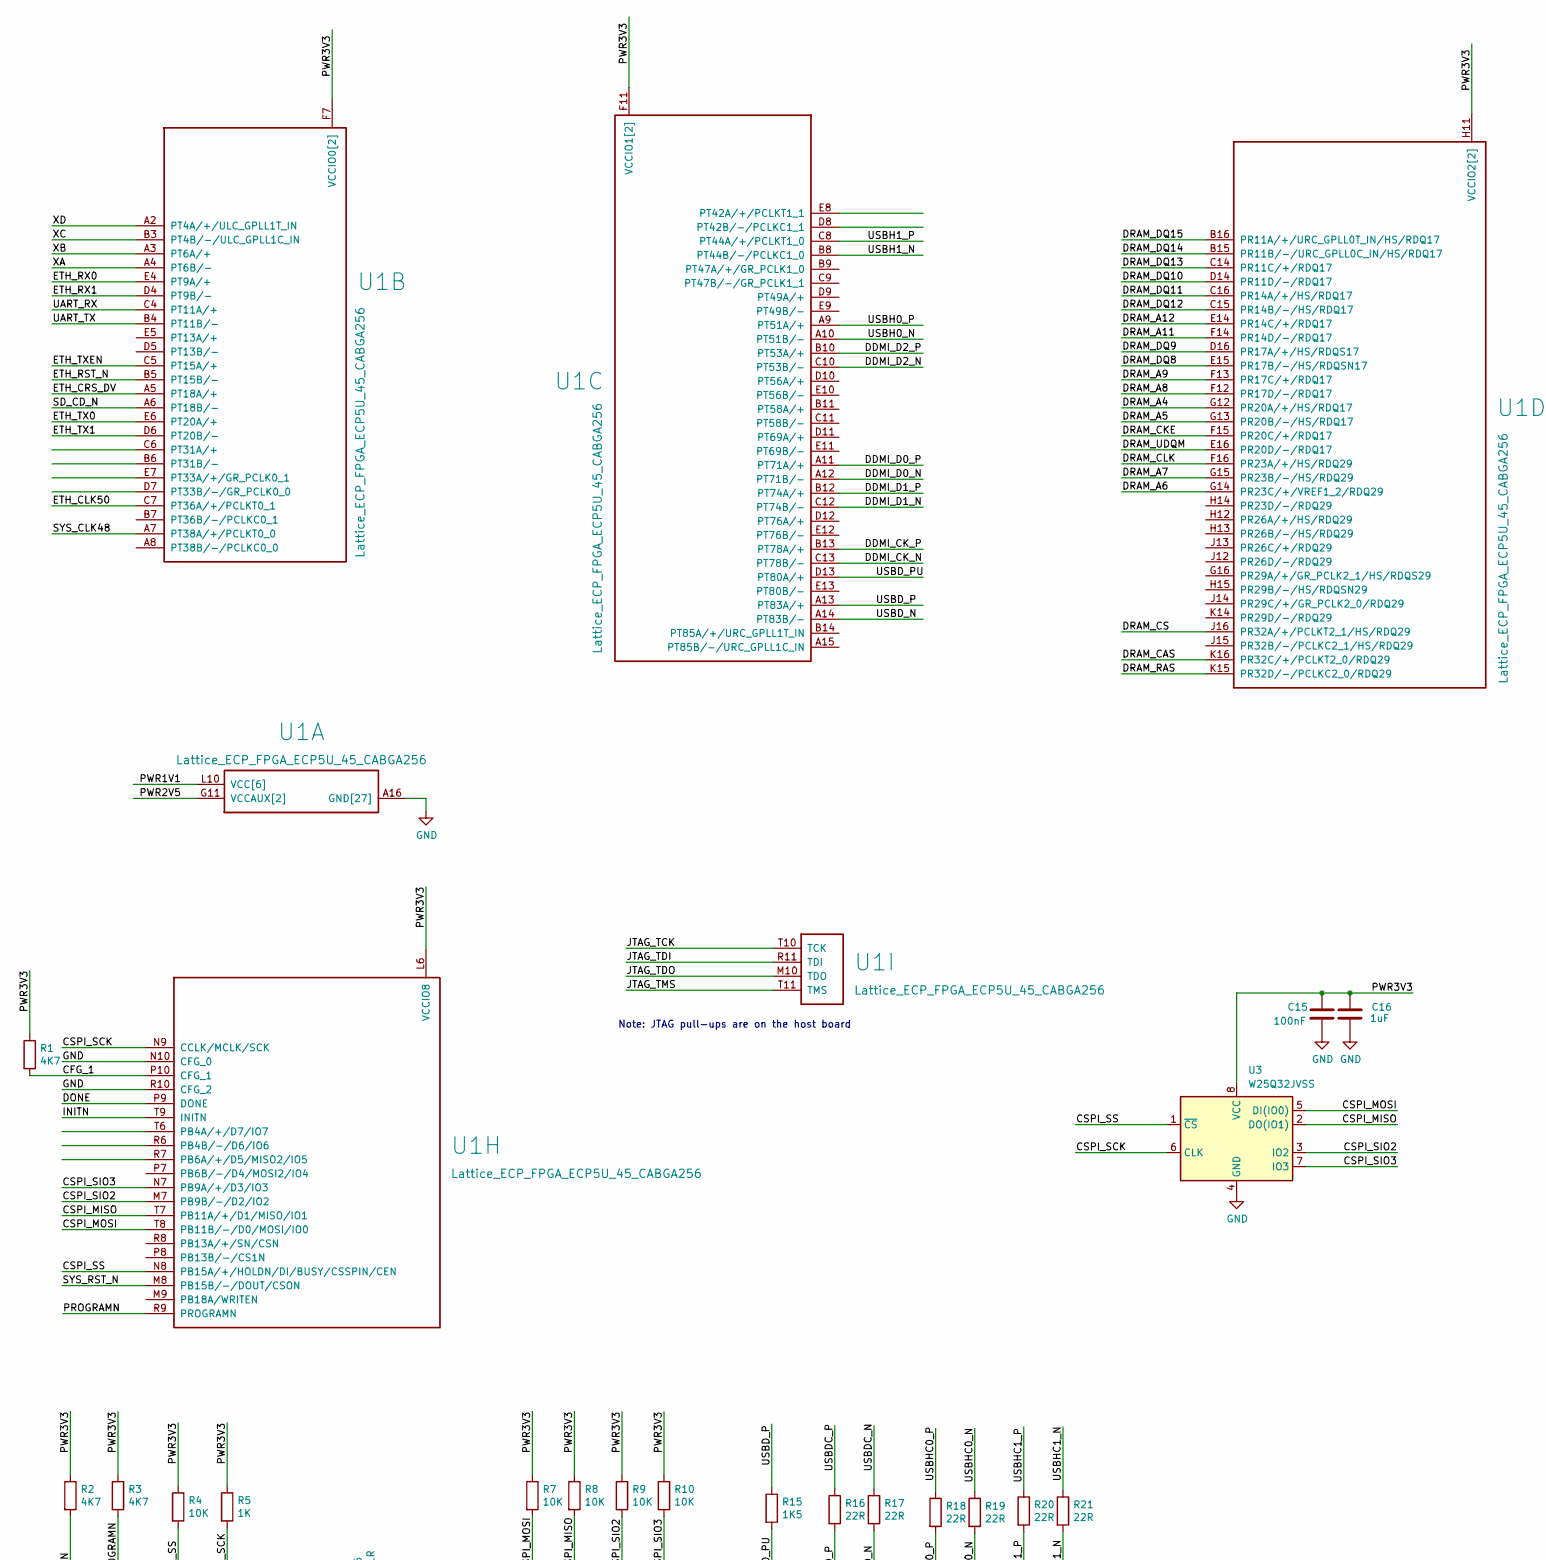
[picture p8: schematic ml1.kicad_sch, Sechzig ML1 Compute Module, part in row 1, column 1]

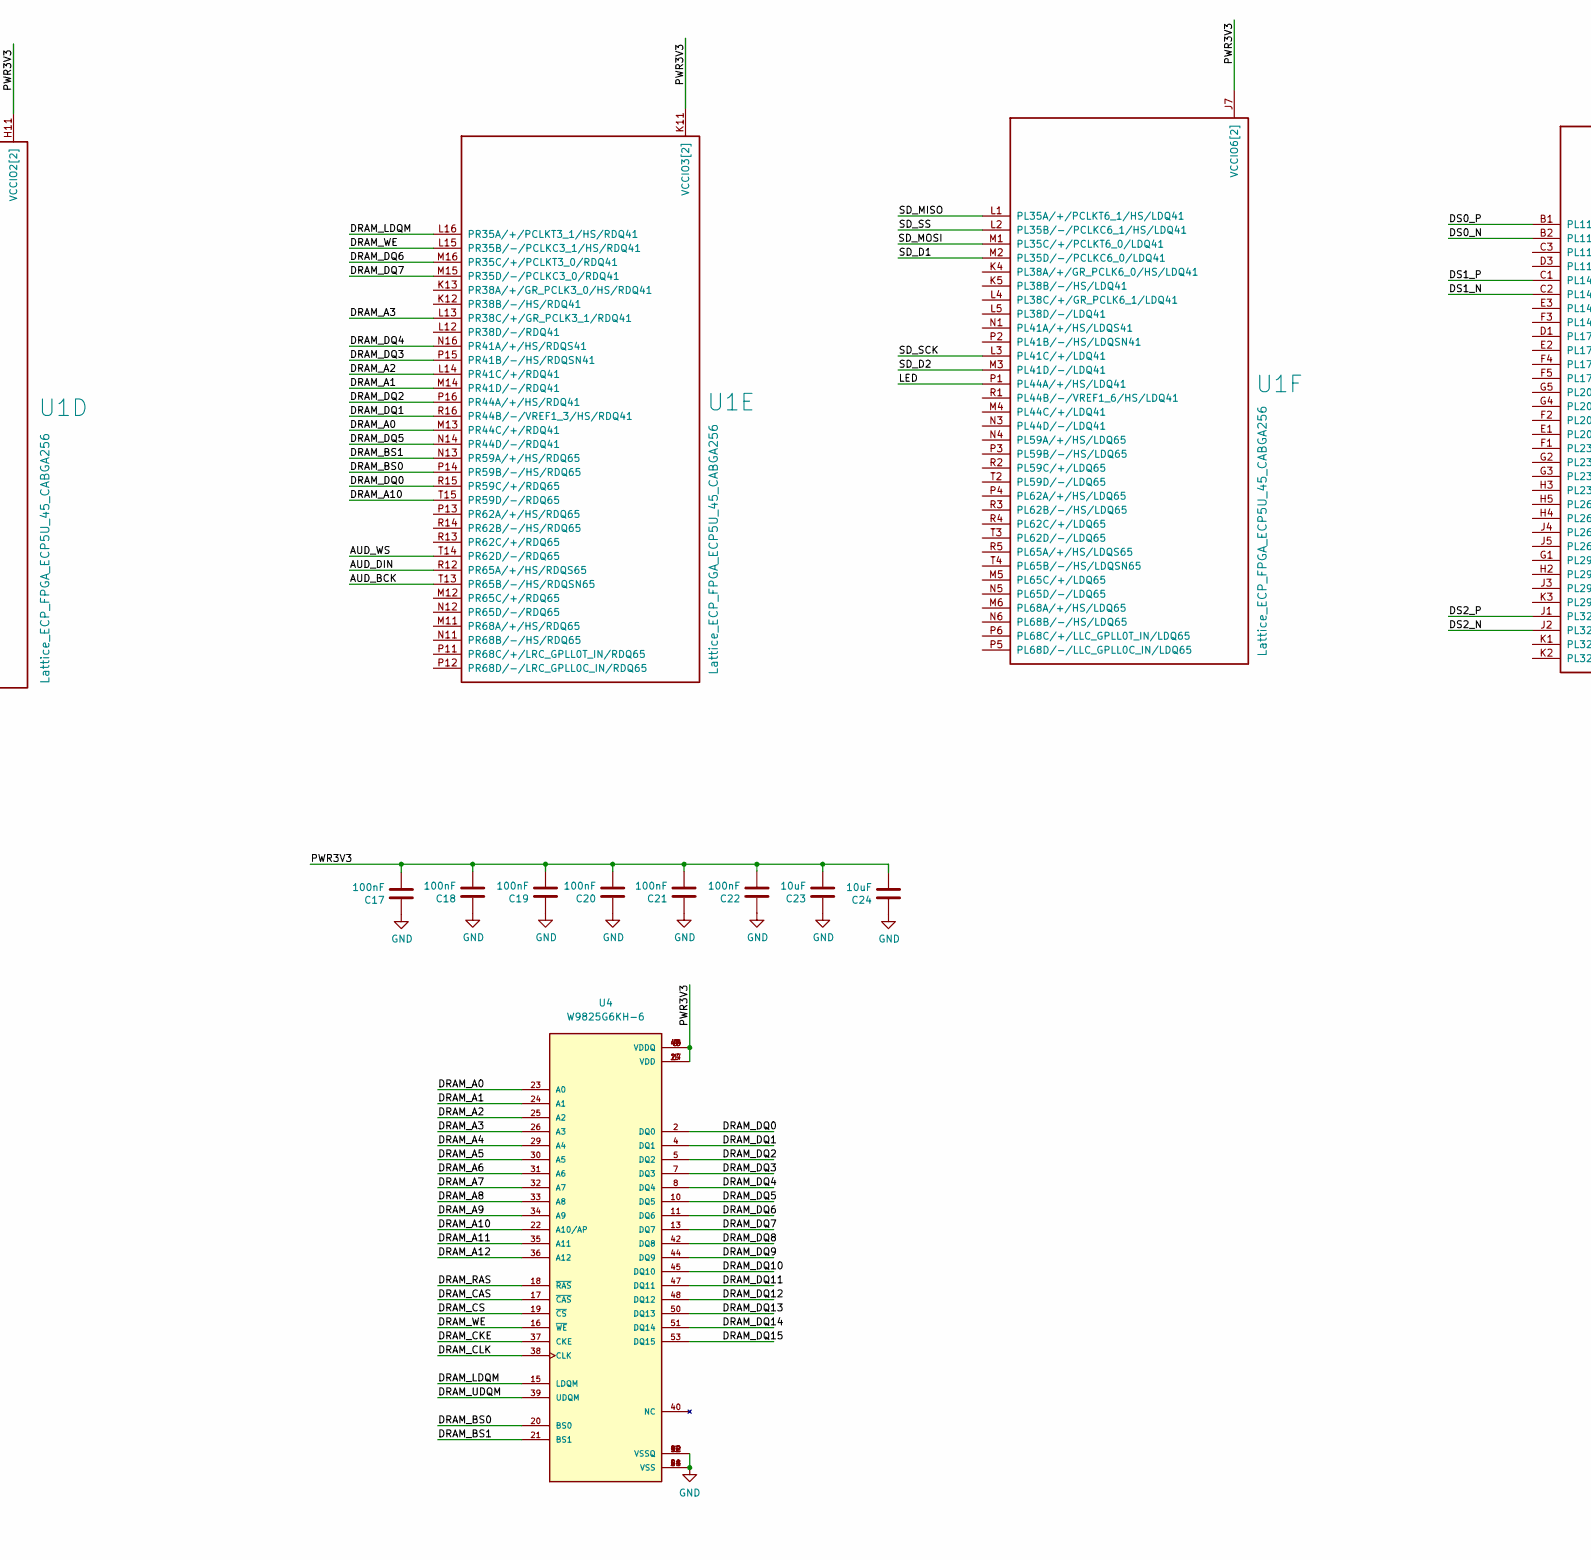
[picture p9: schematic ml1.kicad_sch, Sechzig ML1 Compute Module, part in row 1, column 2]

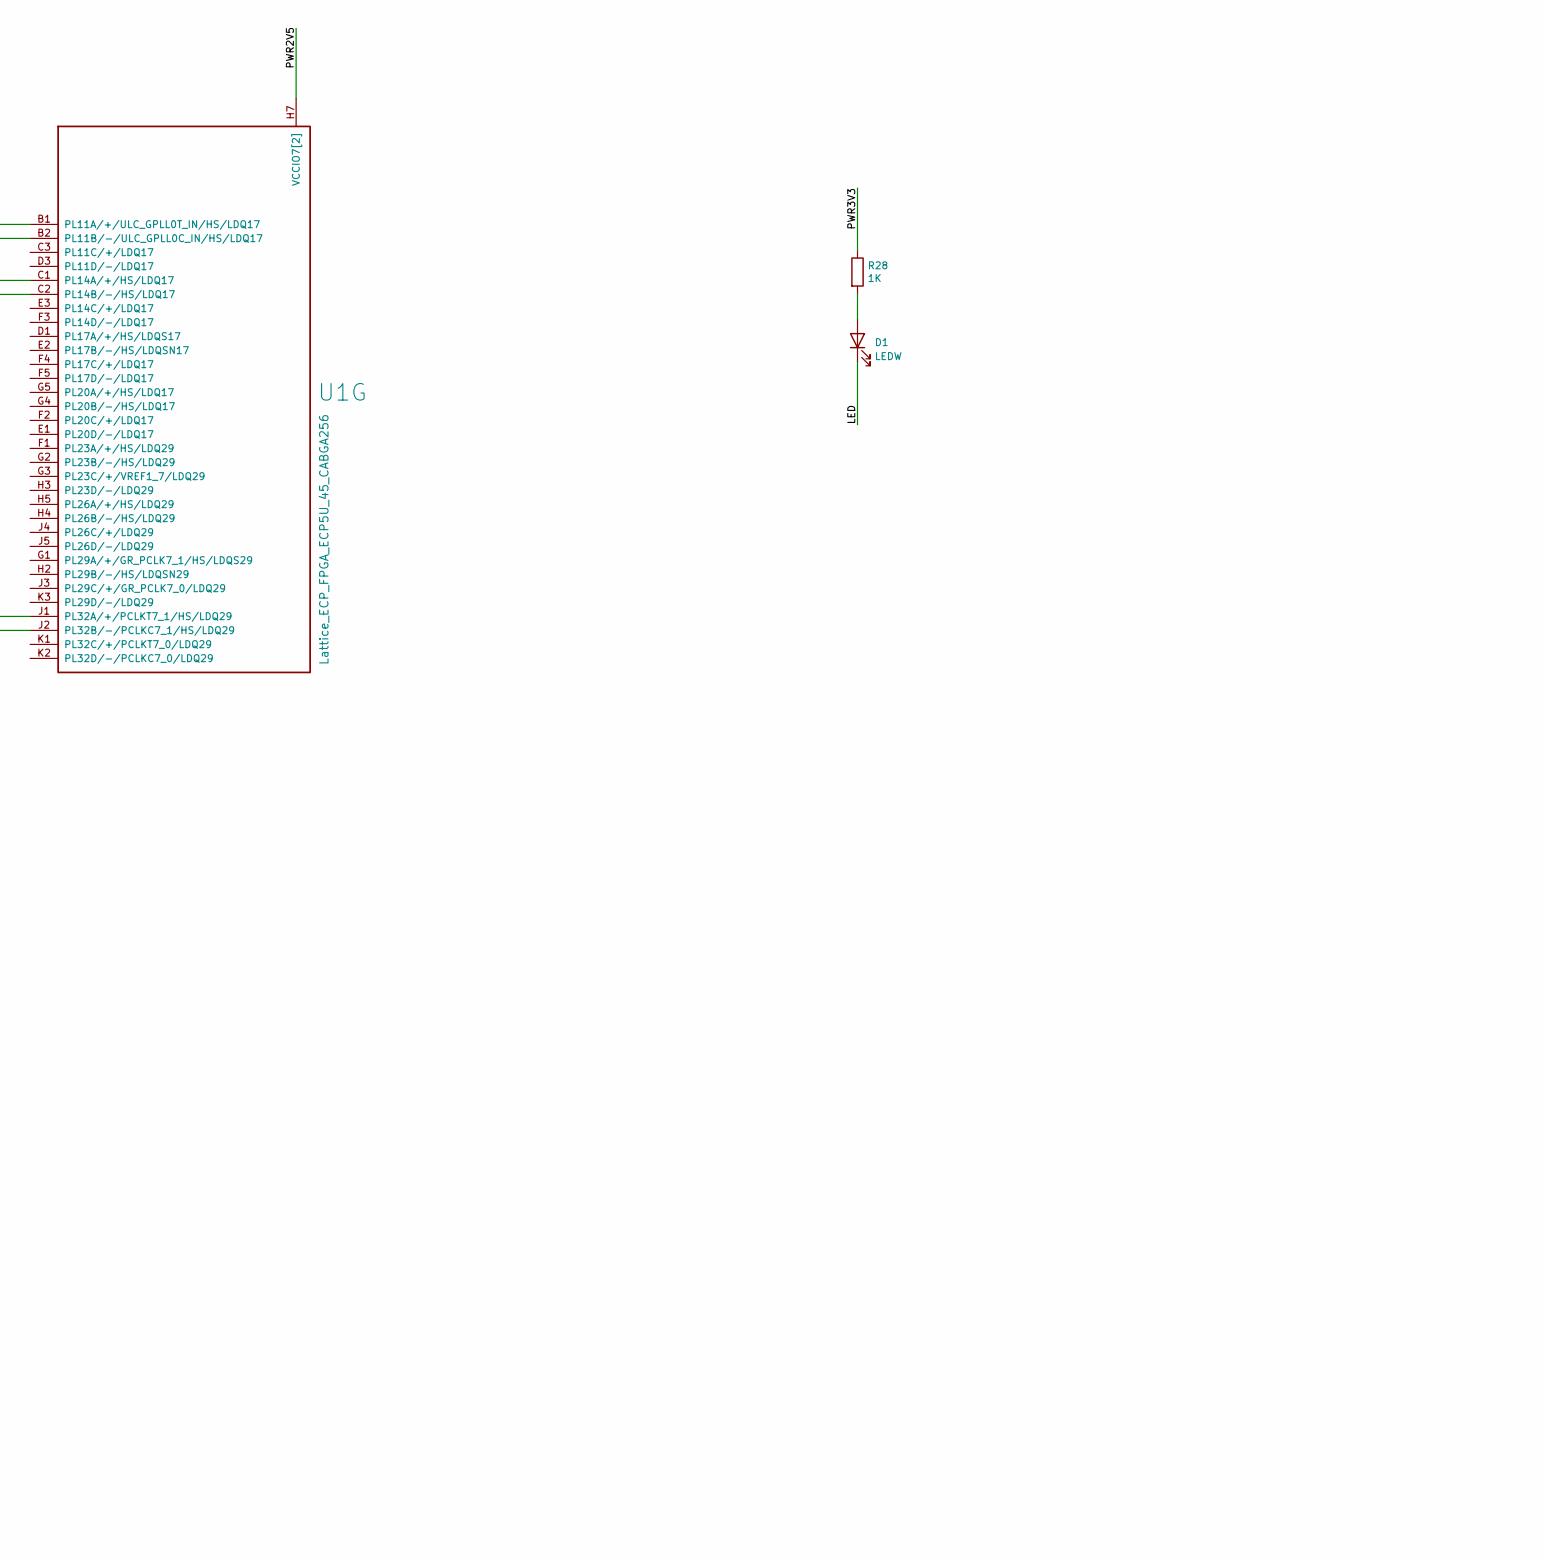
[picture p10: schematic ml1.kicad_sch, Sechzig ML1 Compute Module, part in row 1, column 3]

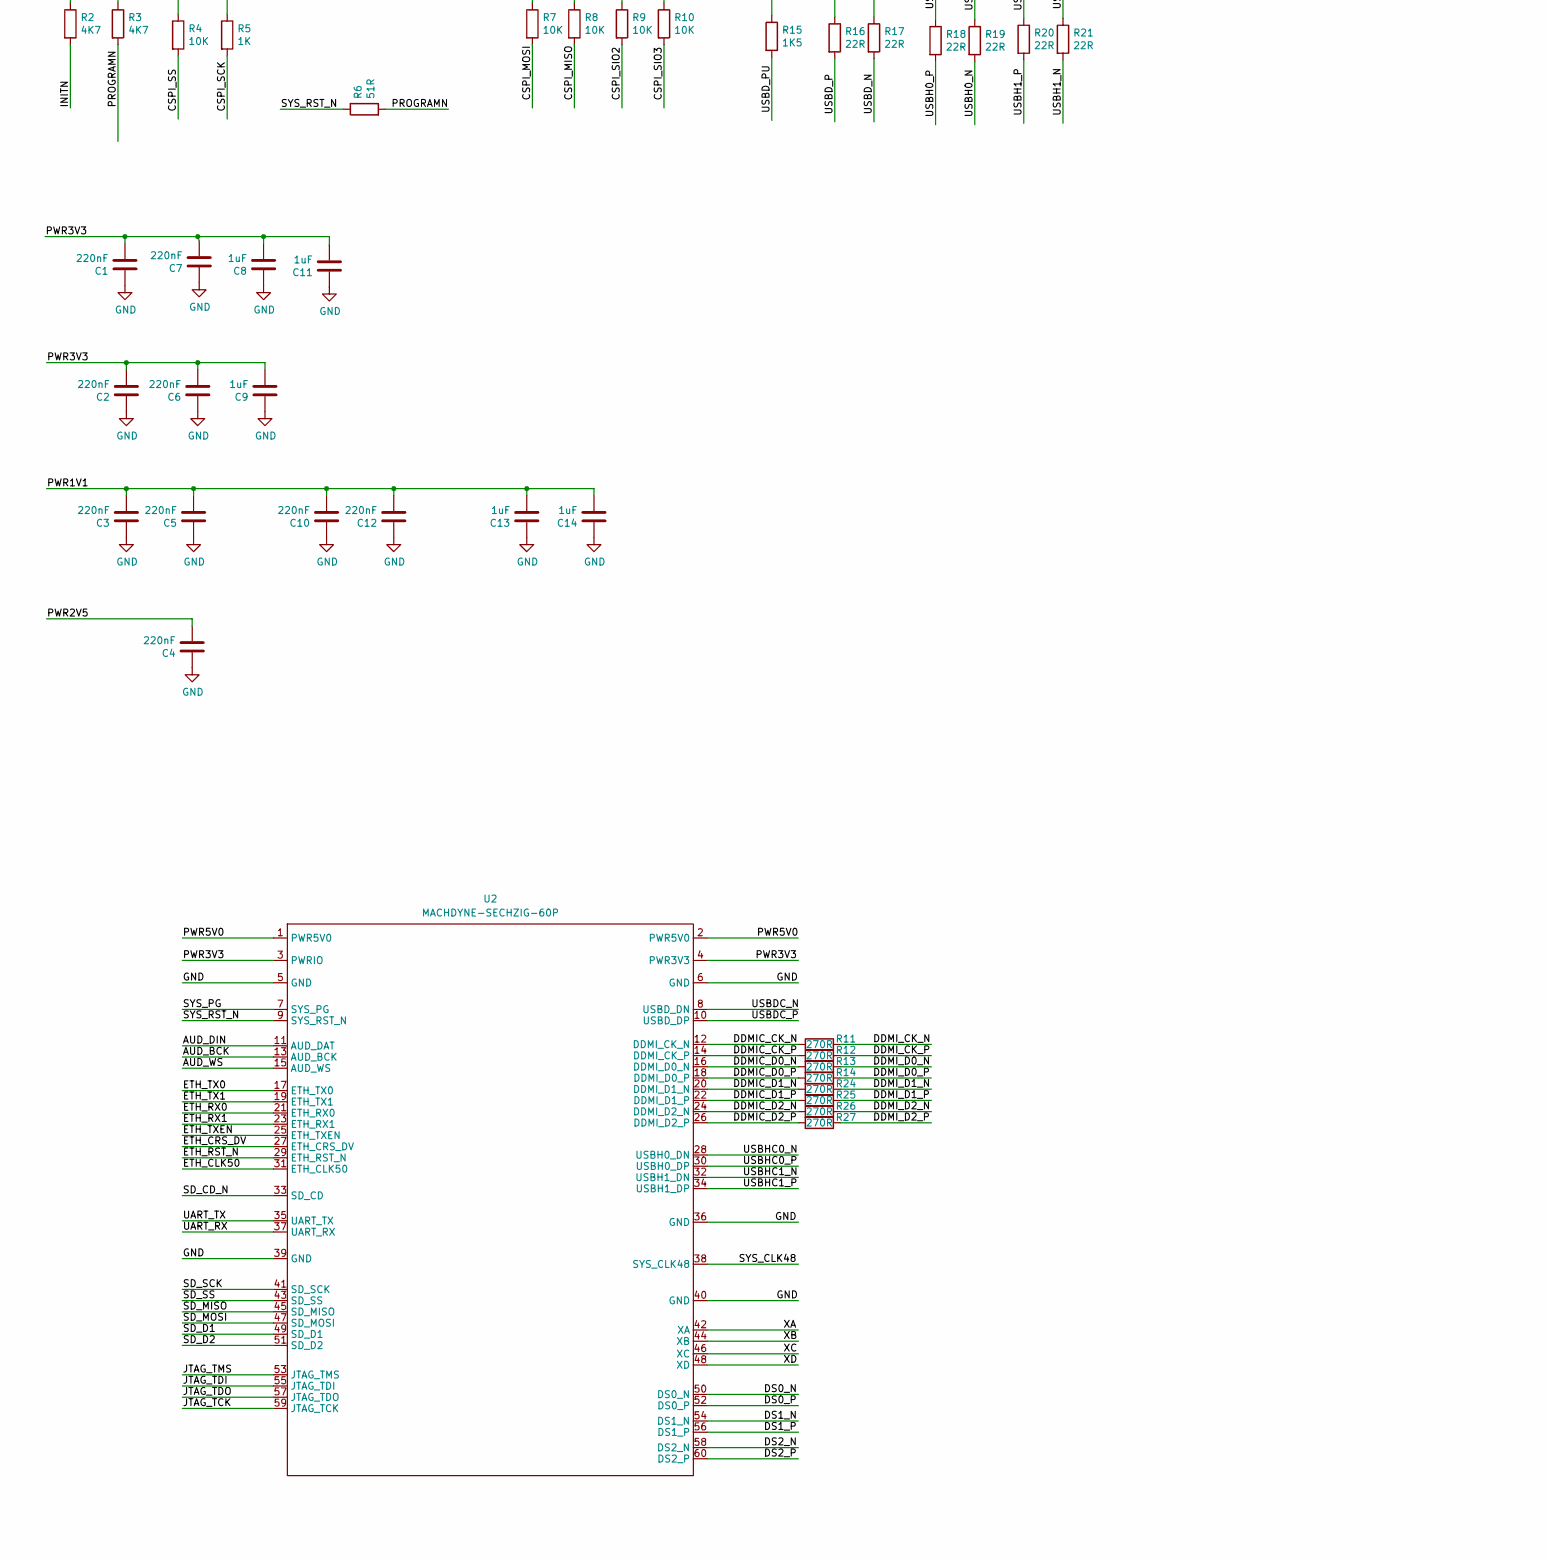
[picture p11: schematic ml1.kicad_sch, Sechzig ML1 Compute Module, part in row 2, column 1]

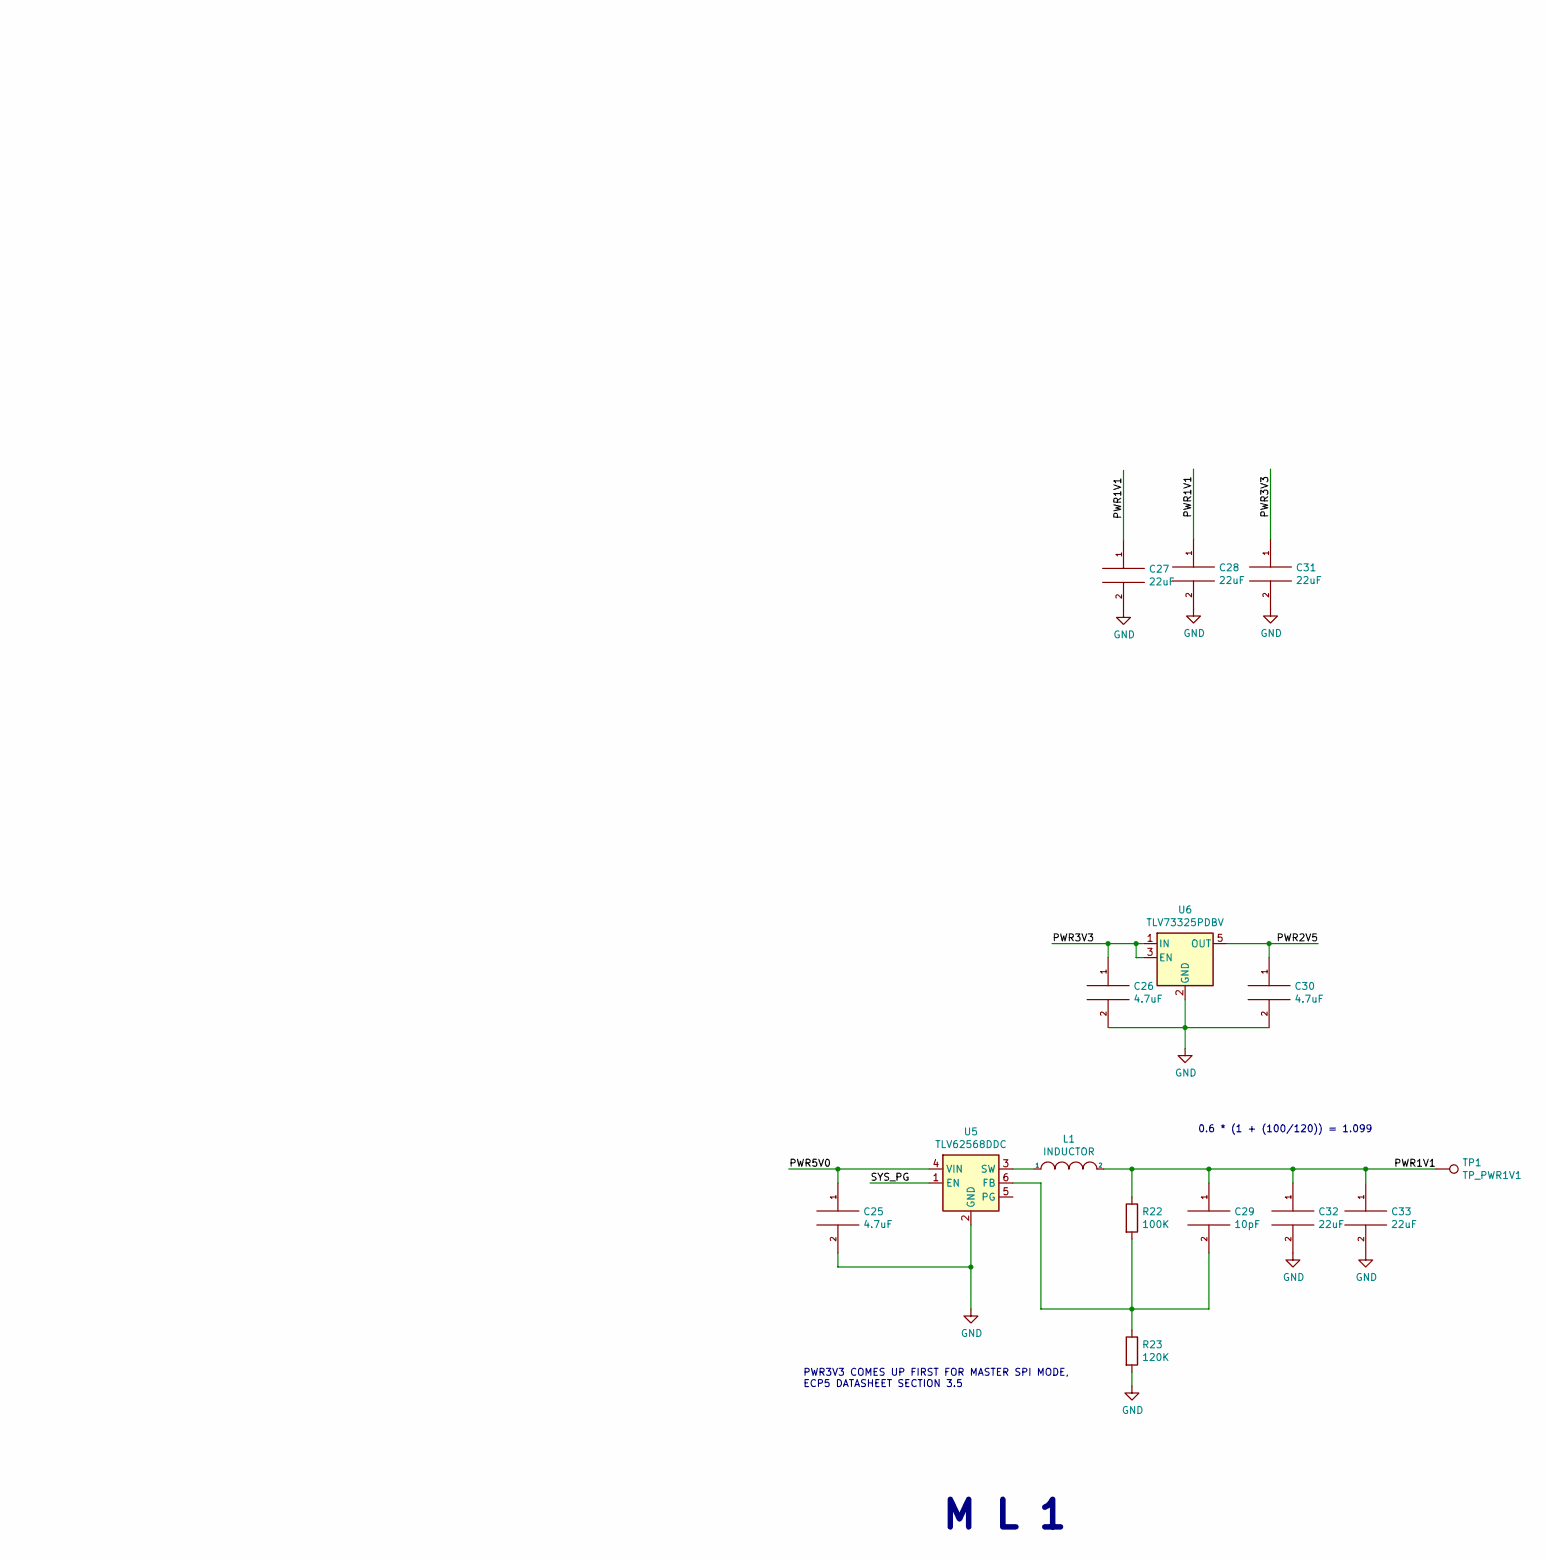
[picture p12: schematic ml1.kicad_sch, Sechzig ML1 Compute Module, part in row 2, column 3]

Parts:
C1, C2, C3, C4, C5, C6, C7, C10, C12: 220nF; C_0603_1608Metric
C8, C9, C11, C13, C14, C16: 1uF; C_0603_1608Metric
C15, C17, C18, C19, C20, C21, C22: 100nF; C_0603_1608Metric
C23, C24: 10uF; C_0603_1608Metric
C25, C26, C30: 4.7uF; C_0603_1608Metric
C27, C28, C31, C32, C33: 22uF; C_0603_1608Metric
C29: 10pF; C_0603_1608Metric
D1: LEDW; LED_0603_1608Metric
L1: INDUCTOR; L_0805_2012Metric
R1, R2, R3: 4K7; R_0603_1608Metric
R4, R7, R8, R9, R10: 10K; R_0603_1608Metric
R5, R28: 1K; R_0603_1608Metric
R6: 51R; R_0603_1608Metric
R11, R12, R13, R14, R24, R25, R26, R27: 270R; R_0402_1005Metric
R15: 1K5; R_0402_1005Metric
R16, R17, R18, R19, R20, R21: 22R; R_0402_1005Metric
R22: 100K; R_0603_1608Metric
R23: 120K; R_0603_1608Metric
TP1: TP_PWR1V1; TestPoint_THTPad_D1.0mm_Drill0.5mm
U1: Lattice_ECP_FPGA_ECP5U_45_CABGA256; BGA-256_14.0x14.0mm_Layout16x16_P0.8mm_Ball0.45mm_Pad0.32mm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
U2: MACHDYNE-SECHZIG-60P; MACHDYNE_EDGE_60P
U3: W25Q32JVSS; SOIC-8_3.9x4.9mm_P1.27mm
U4: W9825G6KH-6; SOP80P1176X120-54N; PARTREV A05
U5: TLV62568DDC; SOT-23-6
U6: TLV73325PDBV; SOT-23-5

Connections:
/AUD_BCK: U1.T13 (PR65B/-/HS/RDQSN65), U2.13 (AUD_BCK)
/AUD_DIN: U1.R12 (PR65A/+/HS/RDQS65), U2.11 (AUD_DAT)
/AUD_WS: U1.T14 (PR62D/-/RDQ65), U2.15 (AUD_WS)
/CFG_1: R1.2, U1.P10 (CFG_1)
/CSPI_MISO: R8.2, U1.T7 (PB11A/+/D1/MISO/IO1), U3.2 (DO(IO1))
/CSPI_MOSI: R7.2, U1.T8 (PB11B/-/D0/MOSI/IO0), U3.5 (DI(IO0))
/CSPI_SCK: R5.2, U1.N9 (CCLK/MCLK/SCK), U3.6 (CLK)
/CSPI_SIO2: R9.2, U1.M7 (PB9B/-/D2/IO2), U3.3 (IO2)
/CSPI_SIO3: R10.2, U1.N7 (PB9A/+/D3/IO3), U3.7 (IO3)
/CSPI_SS: R4.2, U1.N8 (PB15A/+/HOLDN/DI/BUSY/CSSPIN/CEN), U3.1 (~CS)
/DDMIC_CK_N: R11.1, U2.12 (DDMI_CK_N)
/DDMIC_CK_P: R12.1, U2.14 (DDMI_CK_P)
/DDMIC_D0_N: R13.1, U2.16 (DDMI_D0_N)
/DDMIC_D0_P: R14.1, U2.18 (DDMI_D0_P)
/DDMIC_D1_N: R24.1, U2.20 (DDMI_D1_N)
/DDMIC_D1_P: R25.1, U2.22 (DDMI_D1_P)
/DDMIC_D2_N: R26.1, U2.24 (DDMI_D2_N)
/DDMIC_D2_P: R27.1, U2.26 (DDMI_D2_P)
/DDMI_CK_N: R11.2, U1.C13 (PT78B/-)
/DDMI_CK_P: R12.2, U1.B13 (PT78A/+)
/DDMI_D0_N: R13.2, U1.A12 (PT71B/-)
/DDMI_D0_P: R14.2, U1.A11 (PT71A/+)
/DDMI_D1_N: R24.2, U1.C12 (PT74B/-)
/DDMI_D1_P: R25.2, U1.B12 (PT74A/+)
/DDMI_D2_N: R26.2, U1.C10 (PT53B/-)
/DDMI_D2_P: R27.2, U1.B10 (PT53A/+)
/DONE: U1.P9 (DONE)
/DRAM_A0: U1.M13 (PR44C/+/RDQ41), U4.23 (A0)
/DRAM_A1: U1.M14 (PR41D/-/RDQ41), U4.24 (A1)
/DRAM_A2: U1.L14 (PR41C/+/RDQ41), U4.25 (A2)
/DRAM_A3: U1.L13 (PR38C/+/GR_PCLK3_1/RDQ41), U4.26 (A3)
/DRAM_A4: U1.G12 (PR20A/+/HS/RDQ17), U4.29 (A4)
/DRAM_A5: U1.G13 (PR20B/-/HS/RDQ17), U4.30 (A5)
/DRAM_A6: U1.G14 (PR23C/+/VREF1_2/RDQ29), U4.31 (A6)
/DRAM_A7: U1.G15 (PR23B/-/HS/RDQ29), U4.32 (A7)
/DRAM_A8: U1.F12 (PR17D/-/RDQ17), U4.33 (A8)
/DRAM_A9: U1.F13 (PR17C/+/RDQ17), U4.34 (A9)
/DRAM_A10: U1.T15 (PR59D/-/RDQ65), U4.22 (A10/AP)
/DRAM_A11: U1.F14 (PR14D/-/RDQ17), U4.35 (A11)
/DRAM_A12: U1.E14 (PR14C/+/RDQ17), U4.36 (A12)
/DRAM_BS0: U1.P14 (PR59B/-/HS/RDQ65), U4.20 (BS0)
/DRAM_BS1: U1.N13 (PR59A/+/HS/RDQ65), U4.21 (BS1)
/DRAM_CAS: U1.K16 (PR32C/+/PCLKT2_0/RDQ29), U4.17 (~CAS)
/DRAM_CKE: U1.F15 (PR20C/+/RDQ17), U4.37 (CKE)
/DRAM_CLK: U1.F16 (PR23A/+/HS/RDQ29), U4.38 (CLK)
/DRAM_CS: U1.J16 (PR32A/+/PCLKT2_1/HS/RDQ29), U4.19 (~CS)
/DRAM_DQ0: U1.R15 (PR59C/+/RDQ65), U4.2 (DQ0)
/DRAM_DQ1: U1.R16 (PR44B/-/VREF1_3/HS/RDQ41), U4.4 (DQ1)
/DRAM_DQ2: U1.P16 (PR44A/+/HS/RDQ41), U4.5 (DQ2)
/DRAM_DQ3: U1.P15 (PR41B/-/HS/RDQSN41), U4.7 (DQ3)
/DRAM_DQ4: U1.N16 (PR41A/+/HS/RDQS41), U4.8 (DQ4)
/DRAM_DQ5: U1.N14 (PR44D/-/RDQ41), U4.10 (DQ5)
/DRAM_DQ6: U1.M16 (PR35C/+/PCLKT3_0/RDQ41), U4.11 (DQ6)
/DRAM_DQ7: U1.M15 (PR35D/-/PCLKC3_0/RDQ41), U4.13 (DQ7)
/DRAM_DQ8: U1.E15 (PR17B/-/HS/RDQSN17), U4.42 (DQ8)
/DRAM_DQ9: U1.D16 (PR17A/+/HS/RDQS17), U4.44 (DQ9)
/DRAM_DQ10: U1.D14 (PR11D/-/RDQ17), U4.45 (DQ10)
/DRAM_DQ11: U1.C16 (PR14A/+/HS/RDQ17), U4.47 (DQ11)
/DRAM_DQ12: U1.C15 (PR14B/-/HS/RDQ17), U4.48 (DQ12)
/DRAM_DQ13: U1.C14 (PR11C/+/RDQ17), U4.50 (DQ13)
/DRAM_DQ14: U1.B15 (PR11B/-/URC_GPLL0C_IN/HS/RDQ17), U4.51 (DQ14)
/DRAM_DQ15: U1.B16 (PR11A/+/URC_GPLL0T_IN/HS/RDQ17), U4.53 (DQ15)
/DRAM_LDQM: U1.L16 (PR35A/+/PCLKT3_1/HS/RDQ41), U4.15 (LDQM)
/DRAM_RAS: U1.K15 (PR32D/-/PCLKC2_0/RDQ29), U4.18 (~RAS)
/DRAM_UDQM: U1.E16 (PR20D/-/RDQ17), U4.39 (UDQM)
/DRAM_WE: U1.L15 (PR35B/-/PCLKC3_1/HS/RDQ41), U4.16 (~WE)
/DS0_N: U1.B2 (PL11B/-/ULC_GPLL0C_IN/HS/LDQ17), U2.50 (DS0_N)
/DS0_P: U1.B1 (PL11A/+/ULC_GPLL0T_IN/HS/LDQ17), U2.52 (DS0_P)
/DS1_N: U1.C2 (PL14B/-/HS/LDQ17), U2.54 (DS1_N)
/DS1_P: U1.C1 (PL14A/+/HS/LDQ17), U2.56 (DS1_P)
/DS2_N: U1.J2 (PL32B/-/PCLKC7_1/HS/LDQ29), U2.58 (DS2_N)
/DS2_P: U1.J1 (PL32A/+/PCLKT7_1/HS/LDQ29), U2.60 (DS2_P)
/ETH_CLK50: U1.C7 (PT36A/+/PCLKT0_1), U2.31 (ETH_CLK50)
/ETH_CRS_DV: U1.A5 (PT18A/+), U2.27 (ETH_CRS_DV)
/ETH_RST_N: U1.B5 (PT15B/-), U2.29 (ETH_RST_N)
/ETH_RX0: U1.E4 (PT9A/+), U2.21 (ETH_RX0)
/ETH_RX1: U1.D4 (PT9B/-), U2.23 (ETH_RX1)
/ETH_TX0: U1.E6 (PT20A/+), U2.17 (ETH_TX0)
/ETH_TX1: U1.D6 (PT20B/-), U2.19 (ETH_TX1)
/ETH_TXEN: U1.C5 (PT15A/+), U2.25 (ETH_TXEN)
/INITN: R2.2, U1.T9 (INITN)
/JTAG_TCK: U1.T10 (TCK), U2.59 (JTAG_TCK)
/JTAG_TDI: U1.R11 (TDI), U2.55 (JTAG_TDI)
/JTAG_TDO: U1.M10 (TDO), U2.57 (JTAG_TDO)
/JTAG_TMS: U1.T11 (TMS), U2.53 (JTAG_TMS)
/LED: D1.1 (K), U1.P1 (PL44A/+/HS/LDQ41)
/PROGRAMN: R3.2, R6.2, U1.R9 (PROGRAMN)
/PWR1V1: C3.2, C5.2, C10.2, C12.2, C13.2, C14.2, C27.1, C28.1, C29.1, C32.1, C33.1, L1.2, R22.1, TP1.1, U1.G6 (VCC[6]), U1.G7 (VCC[6]), U1.G9 (VCC[6]), U1.L8 (VCC[6]), U1.L9 (VCC[6]), U1.L10 (VCC[6])
/PWR2V5: C4.2, C30.1, U1.G11 (VCCAUX[2]), U1.H6 (VCCIO7[2]), U1.H7 (VCCIO7[2]), U1.L7 (VCCAUX[2]), U6.5 (OUT)
/PWR3V3: C1.2, C2.2, C6.2, C7.2, C8.2, C9.2, C11.2, C15.1, C16.1, C17.2, C18.2, C19.2, C20.2, C21.2, C22.2, C23.2, C24.2, C26.1, C31.1, R1.1, R2.1, R3.1, R4.1, R5.1, R7.1, R8.1, R9.1, R10.1, R28.1, U1.F6 (VCCIO0[2]), U1.F7 (VCCIO0[2]), U1.F10 (VCCIO1[2]), U1.F11 (VCCIO1[2]), U1.H11 (VCCIO2[2]), U1.J6 (VCCIO6[2]), U1.J7 (VCCIO6[2]), U1.J11 (VCCIO2[2]), U1.K11 (VCCIO3[2]), U1.L6 (VCCIO8), U1.L11 (VCCIO3[2]), U2.3 (PWRIO), U2.4 (PWR3V3), U3.8 (VCC), U4.1 (VDD), U4.3 (VDDQ), U4.9 (VDDQ), U4.14 (VDD), U4.27 (VDD), U4.43 (VDDQ), U4.49 (VDDQ), U6.1 (IN), U6.3 (EN)
/PWR5V0: C25.1, U2.1 (PWR5V0), U2.2 (PWR5V0), U5.4 (VIN)
/SD_CD_N: U1.A6 (PT18B/-), U2.33 (SD_CD)
/SD_D1: U1.M2 (PL35D/-/PCLKC6_0/LDQ41), U2.49 (SD_D1)
/SD_D2: U1.M3 (PL41D/-/LDQ41), U2.51 (SD_D2)
/SD_MISO: U1.L1 (PL35A/+/PCLKT6_1/HS/LDQ41), U2.45 (SD_MISO)
/SD_MOSI: U1.M1 (PL35C/+/PCLKT6_0/LDQ41), U2.47 (SD_MOSI)
/SD_SCK: U1.L3 (PL41C/+/LDQ41), U2.41 (SD_SCK)
/SD_SS: U1.L2 (PL35B/-/PCLKC6_1/HS/LDQ41), U2.43 (SD_SS)
/SYS_CLK48: U1.A7 (PT38A/+/PCLKT0_0), U2.38 (SYS_CLK48)
/SYS_PG: U2.7 (SYS_PG), U5.1 (EN)
/SYS_RST_N: R6.1, U1.M8 (PB15B/-/DOUT/CSON), U2.9 (SYS_RST_N)
/UART_RX: U1.C4 (PT11A/+), U2.37 (UART_RX)
/UART_TX: U1.B4 (PT11B/-), U2.35 (UART_TX)
/USBDC_N: R17.1, U2.8 (USBD_DN)
/USBDC_P: R16.1, U2.10 (USBD_DP)
/USBD_N: R17.2, U1.A14 (PT83B/-)
/USBD_P: R15.1, R16.2, U1.A13 (PT83A/+)
/USBD_PU: R15.2, U1.D13 (PT80A/+)
/USBH0_N: R19.2, U1.A10 (PT51B/-)
/USBH0_P: R18.2, U1.A9 (PT51A/+)
/USBH1_N: R21.2, U1.B8 (PT44B/-/PCLKC1_0)
/USBH1_P: R20.2, U1.C8 (PT44A/+/PCLKT1_0)
/USBHC0_N: R19.1, U2.28 (USBH0_DN)
/USBHC0_P: R18.1, U2.30 (USBH0_DP)
/USBHC1_N: R21.1, U2.32 (USBH1_DN)
/USBHC1_P: R20.1, U2.34 (USBH1_DP)
/XA: U1.A4 (PT6B/-), U2.42 (XA)
/XB: U1.A3 (PT6A/+), U2.44 (XB)
/XC: U1.B3 (PT4B/-/ULC_GPLL1C_IN), U2.46 (XC)
/XD: U1.A2 (PT4A/+/ULC_GPLL1T_IN), U2.48 (XD)
GND: C1.1, C2.1, C3.1, C4.1, C5.1, C6.1, C7.1, C8.1, C9.1, C10.1, C11.1, C12.1, C13.1, C14.1, C15.2, C16.2, C17.1, C18.1, C19.1, C20.1, C21.1, C22.1, C23.1, C24.1, C25.2, C26.2, C27.2, C28.2, C30.2, C31.2, C32.2, C33.2, R23.2, U1.A1 (GND[27]), U1.A16 (GND[27]), U1.D2 (GND[27]), U1.D15 (GND[27]), U1.F8 (GND[27]), U1.F9 (GND[27]), U1.G8 (GND[27]), U1.G10 (GND[27]), U1.H1 (GND[27]), U1.H8 (GND[27]), U1.H9 (GND[27]), U1.H10 (GND[27]), U1.H16 (GND[27]), U1.J8 (GND[27]), U1.J9 (GND[27]), U1.J10 (GND[27]), U1.K6 (GND[27]), U1.K7 (GND[27]), U1.K8 (GND[27]), U1.K9 (GND[27]), U1.K10 (GND[27]), U1.N2 (GND[27]), U1.N10 (CFG_0), U1.N15 (GND[27]), U1.R10 (CFG_2), U1.T1 (GND[27]), U1.T5 (GND[27]), U1.T12 (GND[27]), U1.T16 (GND[27]), U2.5 (GND), U2.6 (GND), U2.36 (GND), U2.39 (GND), U2.40 (GND), U3.4 (GND), U4.6 (VSSQ), U4.12 (VSSQ), U4.28 (VSS), U4.41 (VSS), U4.46 (VSSQ), U4.52 (VSSQ), U4.54 (VSS), U5.2 (GND), U6.2 (GND)
unnamed: C29.2, R22.2, R23.1, U5.6 (FB)
unnamed: D1.2 (A), R28.2
unnamed: L1.1, U5.3 (SW)

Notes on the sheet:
M L 1
PWR3V3 COMES UP FIRST FOR MASTER SPI MODE, ECP5 DATASHEET SECTION 3.5
0.6 * (1 + (100/120)) = 1.099
Note: JTAG pull-ups are on the host board

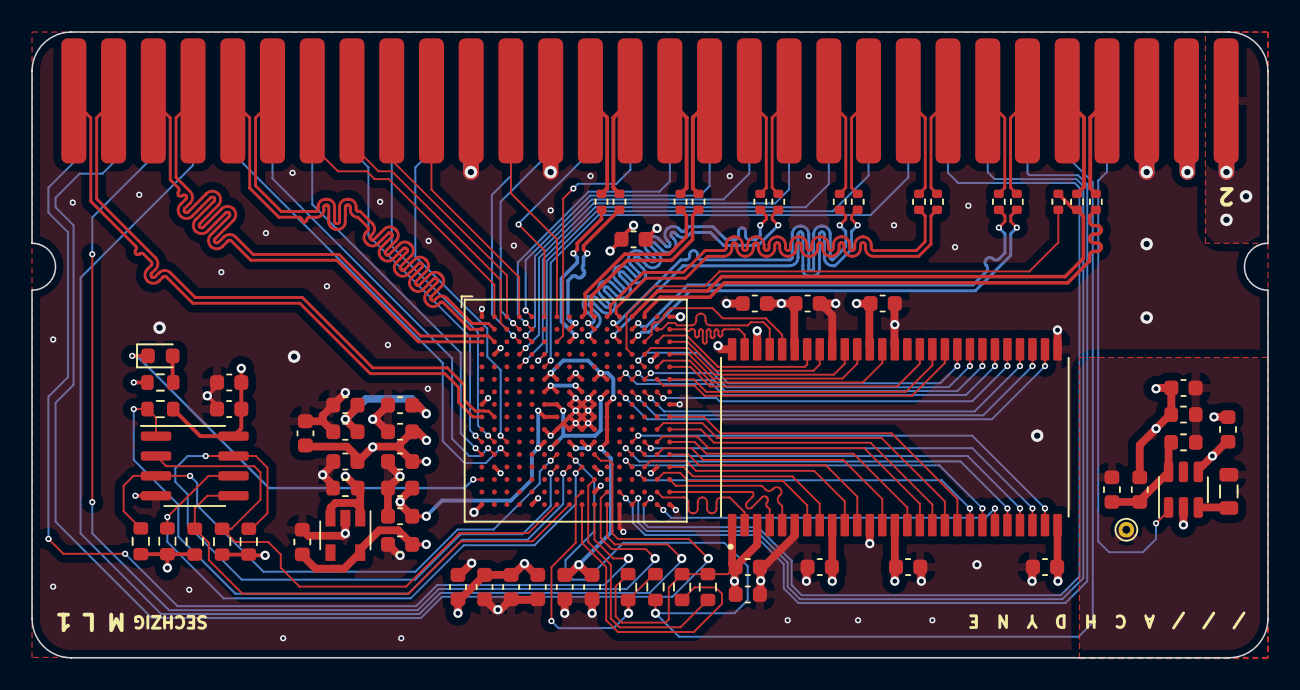
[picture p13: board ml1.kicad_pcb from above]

Board: 4 copper layers, 79.0 x 40.0 mm, 70 parts (1 on the bottom side), 123 nets.

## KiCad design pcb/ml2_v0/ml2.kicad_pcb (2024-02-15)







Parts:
C1, C2, C3, C4, C5, C6, C8, C9, C10, C13: 220nF; C_0603_1608Metric
C7, C11, C12, C15, C16, C43: 1uF; C_0603_1608Metric
C14, C42: 100nF; C_0603_1608Metric
C22, C23, C26, C27, C32, C34, C35, C37: 100nF; C_0402_1005Metric
C24, C29, C30, C38: 1uF; C_0402_1005Metric
C25, C31: 22uF; R_0603_1608Metric
C28: 100nF; R_0603_1608Metric
C44, C48, C50, C54: 4.7uF; C_0603_1608Metric
C45, C52: 10pF; C_0603_1608Metric
C46, C56: 10uF; C_0603_1608Metric
C51, C55, C58: 22uF; C_0603_1608Metric
D1: LED; LED_0603_1608Metric
FB3, FB4: FerriteBead_Small; R_0603_1608Metric
L1, L2: INDUCTOR; L_0805_2012Metric
R1, R2, R3: 4K7; R_0603_1608Metric
R4, R39, R40: 1K; R_0603_1608Metric
R5, R6, R7, R11, R12: 10K; R_0603_1608Metric
R8: 1K5; R_0402_1005Metric
R9, R20, R21: 51R; R_0603_1608Metric
R10, R15, R16, R17, R18, R19: 22R; R_0402_1005Metric
R13, R22, R23, R24, R25, R26, R27, R28: 270R; R_0402_1005Metric
R14: 240R; R_0603_1608Metric
R29: 536R; R_0603_1608Metric
R45: 150K; R_0603_1608Metric
R46, R53: 120K; R_0603_1608Metric
R52: 100K; R_0603_1608Metric
TP2: TP_DRAM_VREF; TestPoint_THTPad_D1.0mm_Drill0.5mm
TP3: TP_PWR1V35; TestPoint_THTPad_D1.0mm_Drill0.5mm
TP4: TP_PWR1V1; TestPoint_THTPad_D1.0mm_Drill0.5mm
U1: Lattice_ECP_FPGA_ECP5U_45_CABGA256; BGA-256_14.0x14.0mm_Layout16x16_P0.8mm_Ball0.45mm_Pad0.32mm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
U2: MACHDYNE-SECHZIG-60P; MACHDYNE_EDGE_60P
U3: MT41K64M16TW-107_J-TR; BGA-96_9.0x13.0mm_Layout2x3x16_P0.8mm_FIXED_SILK
U4: W25Q32JVSS; SOIC-8_3.9x4.9mm_P1.27mm
U5, U6: TLV62568DDC; SOT-23-6
U8: TLV73325PDBV; SOT-23-5

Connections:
/AUD_BCK: U1.E9 (PT49B/-), U2.13 (AUD_BCK)
/AUD_DIN: U1.E10 (PT56B/-), U2.11 (AUD_DAT)
/AUD_WS: U1.D9 (PT49A/+), U2.15 (AUD_WS)
/CFG_1: R1.2, U1.P10 (CFG_1)
/CSPI_MISO: R12.2, U1.T7 (PB11A/+/D1/MISO/IO1), U4.2 (DO(IO1))
/CSPI_MOSI: R11.2, U1.T8 (PB11B/-/D0/MOSI/IO0), U4.5 (DI(IO0))
/CSPI_SCK: R4.2, U1.N9 (CCLK/MCLK/SCK), U4.6 (CLK)
/CSPI_SIO2: R6.2, U1.M7 (PB9B/-/D2/IO2), U4.3 (IO2)
/CSPI_SIO3: R7.2, U1.N7 (PB9A/+/D3/IO3), U4.7 (IO3)
/CSPI_SS: R5.2, U1.N8 (PB15A/+/HOLDN/DI/BUSY/CSSPIN/CEN), U4.1 (~CS)
/DDMIC_CK_N: R13.1, U2.12 (DDMI_CK_N)
/DDMIC_CK_P: R22.1, U2.14 (DDMI_CK_P)
/DDMIC_D0_N: R23.1, U2.16 (DDMI_D0_N)
/DDMIC_D0_P: R24.1, U2.18 (DDMI_D0_P)
/DDMIC_D1_N: R25.1, U2.20 (DDMI_D1_N)
/DDMIC_D1_P: R26.1, U2.22 (DDMI_D1_P)
/DDMIC_D2_N: R27.1, U2.24 (DDMI_D2_N)
/DDMIC_D2_P: R28.1, U2.26 (DDMI_D2_P)
/DDMI_CK_N: R13.2, U1.C10 (PT53B/-)
/DDMI_CK_P: R22.2, U1.B10 (PT53A/+)
/DDMI_D0_N: R23.2, U1.A10 (PT51B/-)
/DDMI_D0_P: R24.2, U1.A9 (PT51A/+)
/DDMI_D1_N: R25.2, U1.B8 (PT44B/-/PCLKC1_0)
/DDMI_D1_P: R26.2, U1.C8 (PT44A/+/PCLKT1_0)
/DDMI_D2_N: R27.2, U1.A12 (PT71B/-)
/DDMI_D2_P: R28.2, U1.A11 (PT71A/+)
/DONE: U1.P9 (DONE)
/DRAM_A0: U1.R15 (PR59C/+/RDQ65), U3.N3 (A0)
/DRAM_A1: U1.L13 (PR38C/+/GR_PCLK3_1/RDQ41), U3.P7 (A1)
/DRAM_A2: U1.P14 (PR59B/-/HS/RDQ65), U3.P3 (A2)
/DRAM_A3: U1.R14 (PR62B/-/HS/RDQ65), U3.N2 (A3)
/DRAM_A4: U1.L12 (PR38D/-/RDQ41), U3.P8 (A4)
/DRAM_A5: U1.T14 (PR62D/-/RDQ65), U3.P2 (A5)
/DRAM_A6: U1.N11 (PR68B/-/HS/RDQ65), U3.R8 (A6)
/DRAM_A7: U1.T13 (PR65B/-/HS/RDQSN65), U3.R2 (A7)
/DRAM_A8: U1.P12 (PR68D/-/LRC_GPLL0C_IN/RDQ65), U3.T8 (A8)
/DRAM_A9: U1.T15 (PR59D/-/RDQ65), U3.R3 (A9)
/DRAM_A10: U1.C14 (PR11C/+/RDQ17), U3.L7 (A10/AP)
/DRAM_A11: U1.M13 (PR44C/+/RDQ41), U3.R7 (A11)
/DRAM_A12: U1.E14 (PR14C/+/RDQ17), U3.N7 (A12/BC#)
/DRAM_A13: U1.R13 (PR62C/+/RDQ65), U3.T3 (A13)
/DRAM_A14: U1.M14 (PR41D/-/RDQ41), U3.T7 (A14)
/DRAM_A15: U1.D14 (PR11D/-/RDQ17), U3.M7 (A15)
/DRAM_BA0: U1.N16 (PR41A/+/HS/RDQS41), U3.M2 (BA0)
/DRAM_BA1: U1.K13 (PR38A/+/GR_PCLK3_0/HS/RDQ41), U3.N8 (BA1)
/DRAM_BA2: U1.P16 (PR44A/+/HS/RDQ41), U3.M3 (BA2)
/DRAM_CAS#: U1.M16 (PR35C/+/PCLKT3_0/RDQ41), U3.K3 (CAS#)
/DRAM_CKE: U1.K12 (PR38B/-/HS/RDQ41), U3.K9 (CKE)
/DRAM_CK_N: R21.2, U1.C15 (PR14B/-/HS/RDQ17), U3.K7 (CK#)
/DRAM_CK_P: R20.2, U1.C16 (PR14A/+/HS/RDQ17), U3.J7 (CK)
/DRAM_CS#: U1.M15 (PR35D/-/PCLKC3_0/RDQ41), U3.L2 (CS#)
/DRAM_DQ0: U1.F14 (PR14D/-/RDQ17), U3.E3 (DQ0)
/DRAM_DQ1: U1.E16 (PR20D/-/RDQ17), U3.F7 (DQ1)
/DRAM_DQ2: U1.F12 (PR17D/-/RDQ17), U3.F2 (DQ2)
/DRAM_DQ3: U1.F15 (PR20C/+/RDQ17), U3.F8 (DQ3)
/DRAM_DQ4: U1.G13 (PR20B/-/HS/RDQ17), U3.H3 (DQ4)
/DRAM_DQ5: U1.B16 (PR11A/+/URC_GPLL0T_IN/HS/RDQ17), U3.H8 (DQ5)
/DRAM_DQ6: U1.G12 (PR20A/+/HS/RDQ17), U3.G2 (DQ6)
/DRAM_DQ7: U1.B15 (PR11B/-/URC_GPLL0C_IN/HS/RDQ17), U3.H7 (DQ7)
/DRAM_DQ8: U1.J14 (PR29C/+/GR_PCLK2_0/RDQ29), U3.D7 (DQ8)
/DRAM_DQ9: U1.J16 (PR32A/+/PCLKT2_1/HS/RDQ29), U3.C3 (DQ9)
/DRAM_DQ10: U1.K15 (PR32D/-/PCLKC2_0/RDQ29), U3.C8 (DQ10)
/DRAM_DQ11: U1.K14 (PR29D/-/RDQ29), U3.C2 (DQ11)
/DRAM_DQ12: U1.H14 (PR23D/-/RDQ29), U3.A7 (DQ12)
/DRAM_DQ13: U1.K16 (PR32C/+/PCLKT2_0/RDQ29), U3.A2 (DQ13)
/DRAM_DQ14: U1.H13 (PR26B/-/HS/RDQ29), U3.B8 (DQ14)
/DRAM_DQ15: U1.J15 (PR32B/-/PCLKC2_1/HS/RDQ29), U3.A3 (DQ15)
/DRAM_LDM: U1.F13 (PR17C/+/RDQ17), U3.E7 (LDM)
/DRAM_LDQS_N: U1.E15 (PR17B/-/HS/RDQSN17), U3.G3 (LDQS#)
/DRAM_LDQS_P: U1.D16 (PR17A/+/HS/RDQS17), U3.F3 (LDQS)
/DRAM_ODT: U1.L15 (PR35B/-/PCLKC3_1/HS/RDQ41), U3.K1 (ODT)
/DRAM_RAS#: U1.L16 (PR35A/+/PCLKT3_1/HS/RDQ41), U3.J3 (RAS#)
/DRAM_RESET#: U1.R12 (PR65A/+/HS/RDQS65), U3.T2 (RESET#)
/DRAM_UDM: U1.J13 (PR26C/+/RDQ29), U3.D3 (UDM)
/DRAM_UDQS_N: U1.H15 (PR29B/-/HS/RDQSN29), U3.B7 (UDQS#)
/DRAM_UDQS_P: U1.G16 (PR29A/+/GR_PCLK2_1/HS/RDQS29), U3.C7 (UDQS)
/DRAM_VDD: C22.1, C23.1, C26.1, C27.1, C29.1, C30.1, C31.1, FB4.1, U3.B2 (VDD[9]), U3.D9 (VDD), U3.G7 (VDD), U3.K2 (VDD), U3.K8 (VDD), U3.N1 (VDD), U3.N9 (VDD), U3.R1 (VDD), U3.R9 (VDD)
/DRAM_VDDQ: C24.1, C25.1, C32.1, C34.1, C35.1, C37.1, C38.1, FB3.1, U3.A1 (VDDQ[9]), U3.A8 (VDDQ), U3.C1 (VDDQ), U3.C9 (VDDQ), U3.D2 (VDDQ), U3.E9 (VDDQ), U3.F1 (VDDQ), U3.H2 (VDDQ), U3.H9 (VDDQ)
/DRAM_VREF: C42.1, C43.1, R39.2, R40.1, TP2.1, U1.G14 (PR23C/+/VREF1_2/RDQ29), U1.R16 (PR44B/-/VREF1_3/HS/RDQ41), U3.H1 (VREFDQ), U3.M8 (VREFCA)
/DRAM_WE#: U1.P15 (PR41B/-/HS/RDQSN41), U3.L3 (WE#)
/DRAM_ZQ: R14.1, U3.L8 (ZQ)
/DS0_N: U1.B2 (PL11B/-/ULC_GPLL0C_IN/HS/LDQ17), U2.50 (DS0_N)
/DS0_P: U1.B1 (PL11A/+/ULC_GPLL0T_IN/HS/LDQ17), U2.52 (DS0_P)
/DS1_N: U1.J2 (PL32B/-/PCLKC7_1/HS/LDQ29), U2.54 (DS1_N)
/DS1_P: U1.J1 (PL32A/+/PCLKT7_1/HS/LDQ29), U2.56 (DS1_P)
/DS2_N: U1.K2 (PL32D/-/PCLKC7_0/LDQ29), U2.58 (DS2_N)
/DS2_P: U1.K1 (PL32C/+/PCLKT7_0/LDQ29), U2.60 (DS2_P)
/ETH_CLK50: U1.A7 (PT38A/+/PCLKT0_0), U2.31 (ETH_CLK50)
/ETH_CRS_DV: U1.E7 (PT33A/+/GR_PCLK0_1), U2.27 (ETH_CRS_DV)
/ETH_RST_N: U1.D7 (PT33B/-/GR_PCLK0_0), U2.29 (ETH_RST_N)
/ETH_RX0: U1.B5 (PT15B/-), U2.21 (ETH_RX0)
/ETH_RX1: U1.B4 (PT11B/-), U2.23 (ETH_RX1)
/ETH_TX0: U1.C6 (PT31A/+), U2.17 (ETH_TX0)
/ETH_TX1: U1.B6 (PT31B/-), U2.19 (ETH_TX1)
/ETH_TXEN: U1.C5 (PT15A/+), U2.25 (ETH_TXEN)
/INITN: R2.2, U1.T9 (INITN)
/JTAG_TCK: U1.T10 (TCK), U2.59 (JTAG_TCK); also elsewhere on the board
/JTAG_TDI: U1.R11 (TDI), U2.55 (JTAG_TDI); also elsewhere on the board
/JTAG_TDO: U1.M10 (TDO), U2.57 (JTAG_TDO); also elsewhere on the board
/JTAG_TMS: U1.T11 (TMS), U2.53 (JTAG_TMS); also elsewhere on the board
/LED: D1.1 (K), U1.T4 (PL65B/-/HS/LDQSN65)
/PROGRAMN: R3.2, R9.2, U1.R9 (PROGRAMN)
/PWR1V1: C2.2, C4.2, C9.2, C10.2, C11.2, C12.2, C51.1, C52.1, C55.1, C56.1, L2.2, R52.1, TP4.1, U1.G6 (VCC[6]), U1.G7 (VCC[6]), U1.G9 (VCC[6]), U1.L8 (VCC[6]), U1.L9 (VCC[6]), U1.L10 (VCC[6])
/PWR1V35: C13.2, C15.2, C45.1, C46.1, FB3.2, FB4.2, L1.2, R39.1, R45.1, TP3.1, U1.H11 (VCCIO2[2]), U1.J11 (VCCIO2[2]), U1.K11 (VCCIO3[2]), U1.L11 (VCCIO3[2])
/PWR2V5: C3.2, C54.1, U1.G11 (VCCAUX[2]), U1.H6 (VCCIO7[2]), U1.H7 (VCCIO7[2]), U1.L7 (VCCAUX[2]), U8.5 (OUT)
/PWR3V3: C1.2, C5.2, C6.2, C7.2, C8.2, C14.1, C16.1, C50.1, C58.1, R1.1, R2.1, R3.1, R4.1, R5.1, R6.1, R7.1, R11.1, R12.1, R29.1, U1.F6 (VCCIO0[2]), U1.F7 (VCCIO0[2]), U1.F10 (VCCIO1[2]), U1.F11 (VCCIO1[2]), U1.J6 (VCCIO6[2]), U1.J7 (VCCIO6[2]), U1.L6 (VCCIO8), U2.3 (PWRIO), U2.4 (PWR3V3), U4.8 (VCC), U8.1 (IN), U8.3 (EN); also elsewhere on the board
/PWR5V0: C44.1, C48.1, U2.1 (PWR5V0), U2.2 (PWR5V0), U5.1 (EN), U5.4 (VIN), U6.4 (VIN)
/SD_CD_N: U1.P2 (PL41B/-/HS/LDQSN41), U2.33 (SD_CD)
/SD_D1: U1.T2 (PL59D/-/LDQ65), U2.49 (SD_D1)
/SD_D2: U1.T3 (PL62D/-/LDQ65), U2.51 (SD_D2)
/SD_MISO: U1.L3 (PL41C/+/LDQ41), U2.45 (SD_MISO)
/SD_MOSI: U1.L4 (PL38C/+/GR_PCLK6_1/LDQ41), U2.47 (SD_MOSI)
/SD_SCK: U1.L1 (PL35A/+/PCLKT6_1/HS/LDQ41), U2.41 (SD_SCK)
/SD_SS: U1.L2 (PL35B/-/PCLKC6_1/HS/LDQ41), U2.43 (SD_SS)
/SYS_CLK48: U1.C7 (PT36A/+/PCLKT0_1), U2.38 (SYS_CLK48)
/SYS_PG: U2.7 (SYS_PG), U6.1 (EN)
/SYS_RST_N: R9.1, U1.M8 (PB15B/-/DOUT/CSON), U2.9 (SYS_RST_N)
/UART_RX: U1.A2 (PT4A/+/ULC_GPLL1T_IN), U2.37 (UART_RX)
/UART_TX: U1.B3 (PT4B/-/ULC_GPLL1C_IN), U2.35 (UART_TX)
/USBDC_N: R15.1, U2.8 (USBD_DN)
/USBDC_P: R10.1, U2.10 (USBD_DP)
/USBD_N: R15.2, U1.A14 (PT83B/-)
/USBD_P: R8.1, R10.2, U1.A13 (PT83A/+)
/USBD_PU: R8.2, U1.B14 (PT85A/+/URC_GPLL1T_IN)
/USBH0_N: R17.2, U1.A6 (PT18B/-)
/USBH0_P: R16.2, U1.A5 (PT18A/+)
/USBH1_N: R19.2, U1.A4 (PT6B/-)
/USBH1_P: R18.2, U1.A3 (PT6A/+)
/USBHC0_N: R17.1, U2.28 (USBH0_DN)
/USBHC0_P: R16.1, U2.30 (USBH0_DP)
/USBHC1_N: R19.1, U2.32 (USBH1_DN)
/USBHC1_P: R18.1, U2.34 (USBH1_DP)
/XA: U1.N1 (PL41A/+/HS/LDQS41), U2.42 (XA)
/XB: U1.P1 (PL44A/+/HS/LDQ41), U2.44 (XB)
/XC: U1.R1 (PL44B/-/VREF1_6/HS/LDQ41), U2.46 (XC)
/XD: U1.R2 (PL59C/+/LDQ65), U2.48 (XD)
GND: C1.1, C2.1, C3.1, C4.1, C5.1, C6.1, C7.1, C8.1, C9.1, C10.1, C11.1, C12.1, C13.1, C14.2, C15.1, C16.2, C22.2, C23.2, C24.2, C25.2, C26.2, C27.2, C28.2, C29.2, C30.2, C31.2, C32.2, C34.2, C35.2, C37.2, C38.2, C42.2, C43.2, C44.2, C46.2, C48.2, C50.2, C51.2, C54.2, C55.2, C56.2, C58.2, R14.2, R40.2, R46.2, R53.2, U1.A1 (GND[27]), U1.A16 (GND[27]), U1.D2 (GND[27]), U1.D15 (GND[27]), U1.F8 (GND[27]), U1.F9 (GND[27]), U1.G8 (GND[27]), U1.G10 (GND[27]), U1.H1 (GND[27]), U1.H8 (GND[27]), U1.H9 (GND[27]), U1.H10 (GND[27]), U1.H16 (GND[27]), U1.J8 (GND[27]), U1.J9 (GND[27]), U1.J10 (GND[27]), U1.K6 (GND[27]), U1.K7 (GND[27]), U1.K8 (GND[27]), U1.K9 (GND[27]), U1.K10 (GND[27]), U1.N2 (GND[27]), U1.N10 (CFG_0), U1.N15 (GND[27]), U1.R10 (CFG_2), U1.T1 (GND[27]), U1.T5 (GND[27]), U1.T12 (GND[27]), U1.T16 (GND[27]), U2.5 (GND), U2.6 (GND), U2.36 (GND), U2.39 (GND), U2.40 (GND), U3.A9 (VSS[12]), U3.B1 (VSSQ[9]), U3.B3 (VSS), U3.B9 (VSSQ), U3.D1 (VSSQ), U3.D8 (VSSQ), U3.E1 (VSS), U3.E2 (VSSQ), U3.E8 (VSSQ), U3.F9 (VSSQ), U3.G1 (VSSQ), U3.G9 (VSSQ), U3.J2 (VSS), U3.J8 (VSS), U3.M1 (VSS), U3.M9 (VSS), U3.P1 (VSS), U3.P9 (VSS), U3.T1 (VSS), U3.T9 (VSS), U4.4 (GND), U5.2 (GND), U6.2 (GND), U8.2 (GND); also elsewhere on the board
unnamed: C28.1, R20.1, R21.1
unnamed: C45.2, R45.2, R46.1, U5.6 (FB)
unnamed: C52.2, R52.2, R53.1, U6.6 (FB)
unnamed: D1.2 (A), R29.2
unnamed: L1.1, U5.3 (SW)
unnamed: L2.1, U6.3 (SW)

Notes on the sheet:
SECHZIG ML2
PWR3V3 COMES UP FIRST FOR MASTER SPI MODE, ECP5 DATASHEET SECTION 3.5
0.6 * (1 + (100/120)) = 1.099
0.6 * (1 + (150/120)) = 1.35


Board: 6 copper layers, 79.0 x 40.0 mm, 98 parts (1 on the bottom side), 142 nets.

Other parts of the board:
R38, R42, R43, R44: 4K7; R_0603_1608Metric

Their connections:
/JTAG_TCK: R44.1; also elsewhere on the board
/JTAG_TDI: R38.2; also elsewhere on the board
/JTAG_TDO: R42.2; also elsewhere on the board
/JTAG_TMS: R43.2; also elsewhere on the board
/PWR3V3: R38.1, R42.1, R43.1; also elsewhere on the board
GND: R44.2; also elsewhere on the board

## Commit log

2023-06-23 update for v1 boards
2023-10-25 update kicad symbol
2023-11-14 add sechzig ml1 schematics and pcb layout
    [ml1.kicad_pcb, ml1.kicad_sch]
2023-12-04 add preliminary cart design
    [sechzig.scad]
2023-12-17 update case
    [sechzig.scad]
2024-02-15 add ml2 pcb
    [ml1.kicad_pcb, ml1.kicad_sch, ml2.kicad_pcb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]
2024-03-06 add mx1 pcb
    [mx1.kicad_pcb, mx1.kicad_sch]
2024-03-07 add ml1.2 pcb
    [ml1.kicad_pcb, ml1.kicad_sch]
2024-07-25 add mx2
    [mx2.kicad_pcb, mx2.kicad_sch]
2024-09-29 add 3d-printable tray for holding modules
    [sechzig_tray.scad]

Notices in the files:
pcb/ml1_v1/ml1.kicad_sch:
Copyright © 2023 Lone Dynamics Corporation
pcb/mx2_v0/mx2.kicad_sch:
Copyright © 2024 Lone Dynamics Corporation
